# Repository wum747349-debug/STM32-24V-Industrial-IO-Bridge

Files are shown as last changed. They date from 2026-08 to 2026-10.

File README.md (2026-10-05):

# STM32 24V Industrial I/O Bridge

Project Identity: wum747349-debug/STM32-24V-Industrial-IO-Bridge

Hardware Revision: Rev.C

Hardware Status: Fabricated / PCBA Assembled / Basic Functional Bring-up Completed / In Practical Use

Current Project Stage: Stage 6 — Routing and Copper

面向 24 V 工业现场的 STM32 I/O interface / bridge board，连接 PC、板载隔离 USB-UART、STM32、CM35 运动控制器和 4 路 AN-LS18-40-N 光电开关。Rev.C 将 STM32 最小系统、USB-C 通信、数字隔离、现场 I/O 和 24 V 电源保护集成在一块 100 mm × 80 mm PCB 上。

```text
24 V Industrial Power
        |
        v
Input Protection / 24 V -> 3.3 V
        |
        v
      STM32
        |-- Isolated USB-UART (USB-C / CH340C / ISO7721)
        |-- CM35 Motion-controller I/O
        `-- Photoelectric Sensor Interfaces (NO / NC)
```

## Hardware Gallery

| PCB Top | PCB Bottom |
| --- | --- |
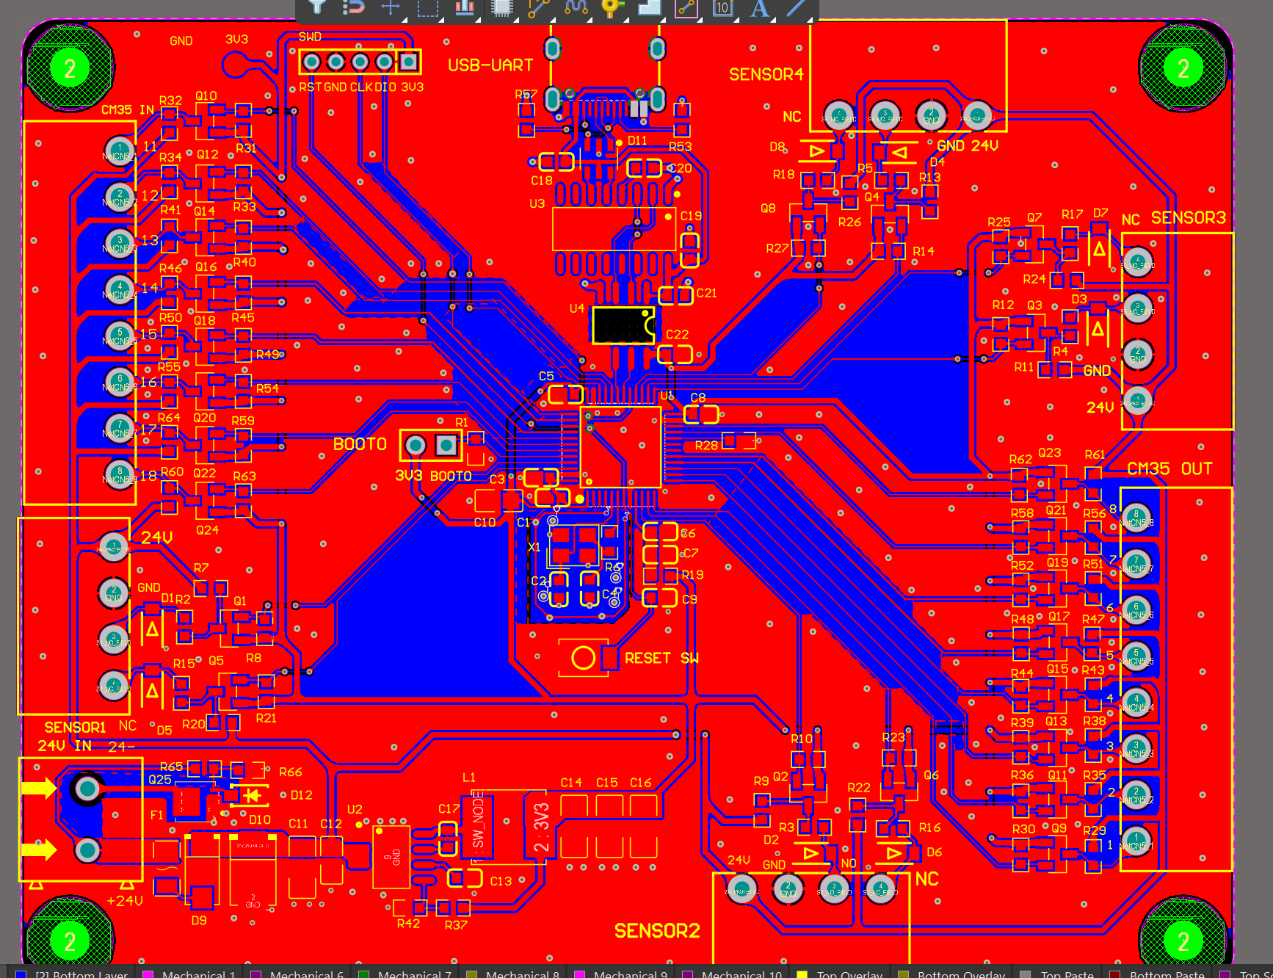
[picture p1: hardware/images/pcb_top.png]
PCB Top
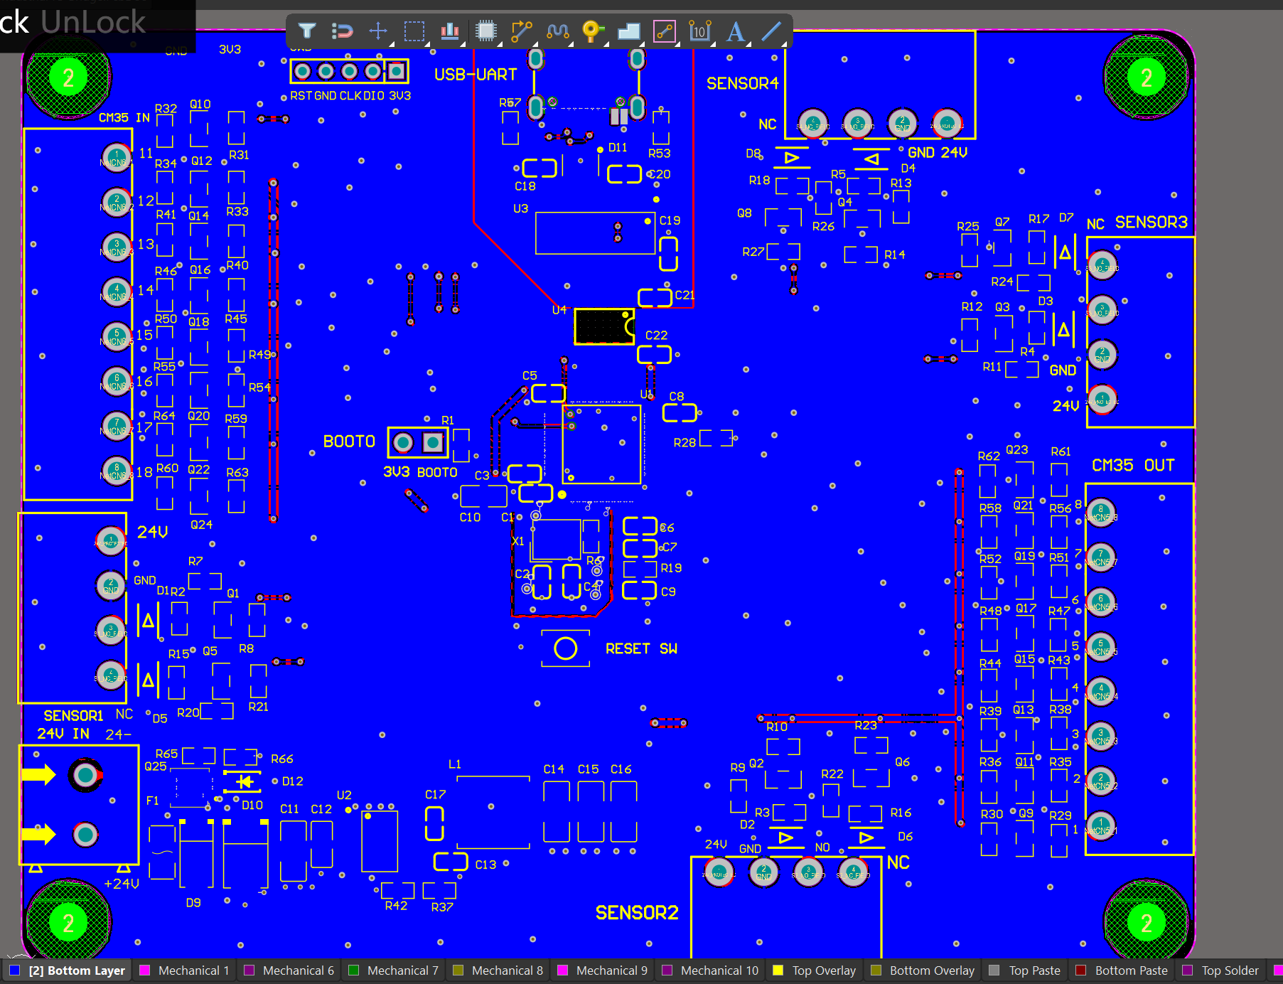
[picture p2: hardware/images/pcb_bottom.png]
PCB Bottom
|  |  |

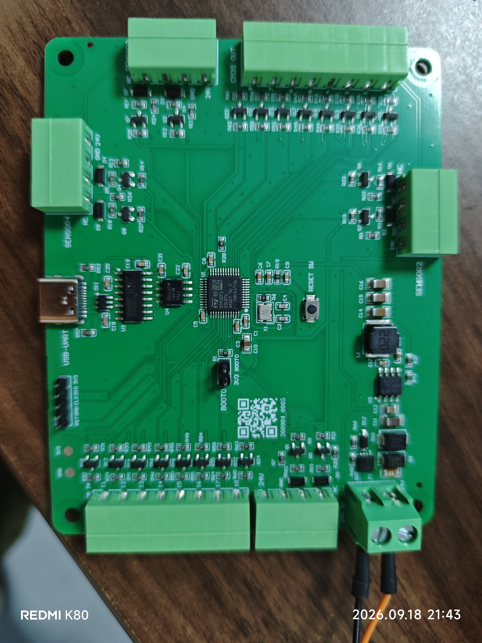
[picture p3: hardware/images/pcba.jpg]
Rev.C PCBA


## Engineering Highlights

- 24 V industrial input with reverse-polarity and input protection, plus onboard 24 V → 3.3 V conversion
- Onboard STM32F103C8T6 minimum system with SWD, reset, BOOT0, HSE, and accessible 3V3/GND test points
- USB-C + CH340C USB-UART with ISO7721 digital isolation and separated USB-side / machine-side ground domains
- Eight CM35 control outputs and eight CM35 status inputs for 24 V industrial I/O
- Four photoelectric-sensor interfaces with field-side power and NO / NC signal paths
- Two-layer PCB layout, signal/power routing, copper pours, isolation corridor, mask normalization, and production-oriented silkscreen
- JLCPCB fabrication / top-side PCBA workflow, followed by board bring-up and practical functional debugging

## Rev.C Hardware Evolution

Rev.C is the third hardware iteration and the current physical implementation. Compared with the previous revision, it:

- adds photoelectric-sensor field power and NO / NC signal interfaces;
- adds onboard USB-C and CH340C USB-UART communication;
- adds ISO7721 isolation between USB-side and machine-side domains;
- replaces the external STM32 minimum-system module with an onboard STM32 minimum system; and
- adds or improves 24 V reverse-polarity, input, and onboard power-conversion protection boundaries.

Detailed revision scope and evidence limits are recorded in [Hardware Revision History](docs/revision_history.md).

## Bring-up and Validation Status

### Confirmed

- Rev.C PCB and assembled PCBA exist and are represented by the images above.
- Basic 24 V power-on and board-level 3.3 V checking were completed.
- STM32 programming through ST-Link was completed.
- Host UART communication was completed at the basic functional-debug level.
- Industrial I/O basic control and terminal-voltage behavior were debugged.
- The board is currently in practical use.

### Not formally documented or claimed

- Complete channel-by-channel quantitative testing
- Quantified input current, startup waveform, ripple, or full-load characterization
- Abnormal-supply qualification
- EMC or surge PASS
- Isolation-withstand PASS
- Complete system acceptance PASS
- Production qualification or product certification

Rev.C has completed practical functional bring-up and is currently in use. Formal quantified validation remains bounded to the evidence documented in this repository; EMC/surge, isolation withstand, full electrical characterization, and complete system acceptance are not claimed. See the [Bring-up Record](docs/bringup_log.md) for the actual sequence, known results, limitations, and recommended future test plan.

## Engineering Status and Evidence Boundaries

- Requirements, component selection, module design, and formal schematic review records are retained in the repository. Stage 4 Formal Schematic Review is recorded as `PASS / CLOSED`, but the project does not claim full-board ERC PASS.
- Full-board placement was closed against the 100 mm × 80 mm mechanical baseline. Stage 6 signal/power routing, polygons, isolation corridor, and finalization work reached final-review level; the lifecycle stage remains **Stage 6 — Routing and Copper**.
- Final DRC on 2026-09-04 reported **0 warnings / 76 rule violations**. The remaining violations were classified as 4 intentional M3 NPTH/keepout scope collisions, 66 minimum solder-mask slivers, and 6 intentional HSE GND-guard net antennae.
- **Final DRC was not zero-violation.** The remaining findings were categorized and reviewed, but this repository does not declare a formal `DRC PASS`.
- JLCPCB production artwork and the PCB/PCBA order were released in September 2026. That historical release state does not replace current hardware-test evidence.
- A minor mechanical note remains for confirming the CN5 / lower-right M3 fastener and removable-terminal envelope with 3D, courtyard, or physical mechanical evidence.

## Repository Navigation

| Area | Record |
| --- | --- |
| Requirements | [requirements.md](requirements.md) |
| Block Diagram | [block_diagram.md](block_diagram.md) |
| Design Notes | [design_notes.md](design_notes.md) |
| Reference Index | [references.md](references.md) |
| Component Selection | [docs/component_selection_plan.md](docs/component_selection_plan.md) |
| Module Design | [docs/module_design/](docs/module_design/) |
| Schematic Review | [docs/schematic_review.md](docs/schematic_review.md) |
| PCB Design Rules | [docs/pcb_design_rules.md](docs/pcb_design_rules.md) |
| PCB Review / DRC / Manufacturing Record | [docs/pcb_review.md](docs/pcb_review.md) |
| Bring-up | [docs/bringup_log.md](docs/bringup_log.md) |
| Revision History | [docs/revision_history.md](docs/revision_history.md) |
| Hardware Sources and Evidence | [hardware/README.md](hardware/README.md) |
| Altium Source Project | [hardware/altium_project/](hardware/altium_project/) |
| Schematic PDF | [hardware/outputs/SCH_Schematic1_2026-09-01.pdf](hardware/outputs/SCH_Schematic1_2026-09-01.pdf) |
| BOM | [hardware/outputs/BOM_Board1_Schematic1_2026-09-01.xlsx](hardware/outputs/BOM_Board1_Schematic1_2026-09-01.xlsx) |
| Framework Binding | [FRAMEWORK.md](FRAMEWORK.md) |
| Project Rules | [PROJECT_RULES.md](PROJECT_RULES.md) |
| Project Validator | [scripts/validate_project_repository.py](scripts/validate_project_repository.py) |

## Current Source and Evidence Set

The current Rev.C Altium project source is versioned under `hardware/altium_project/`. The project file, schematic, PCB, and required project-local libraries are included; generated History, logs, previews, project outputs, manufacturing archives, and temporary files are excluded.

The current Stage 4 schematic PDF and BOM remain under `hardware/outputs/`. Images are presentation and physical-hardware evidence; they do not independently prove connectivity, ERC/DRC status, isolation rating, or quantified electrical performance.

## Next Evidence Work

Future work can add traceable, quantified power measurements, USB-UART power-sequence checks, complete industrial-I/O and sensor channel records, and a formal test report with explicit limits. This portfolio finalization does not perform a Stage transition or convert recommended tests into completed results.

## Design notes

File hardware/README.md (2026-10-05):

# Hardware Sources and Evidence（硬件源与证据）

只有相应工作或 Evidence 真实存在时才创建 hardware 子目录：

- `altium_project/`：权威 `.PrjPcb`、`.SchDoc`、`.PcbDoc` 与必要 Project libraries；
- `outputs/`：可追溯的 schematic PDF、BOM、reports 与 manufacturing outputs；
- `images/`：Review、Assembly、Bring-up、Test 与展示图片。

`.SchDoc` 与 `.PcbDoc` 是权威 EDA implementation sources。目录、PDF、图片或书面设计意图不能证明 ERC、DRC、rule matching、copper state 或 manufacturing release。用户负责实际 Altium 操作与导出；AI/Codex 只在明确限制内分析用户提供的 Evidence。

不得仅为让目录看起来完整而创建空 output 分类或低信息量 placeholder 文件。

## Current Rev.C Altium Source Set

The versioned source set is limited to the files required by the current `STM32 24V Industrial IO Bridge.PrjPcb` project:

- `altium_project/P1.schdoc`
- `altium_project/PCB1.PcbLib`
- `altium_project/STM32 24V Industrial IO Bridge.SCHLIB`
- `altium_project/STM32 24V Industrial IO Bridge/STM32 24V Industrial IO Bridge.PrjPcb`
- `altium_project/STM32 24V Industrial IO Bridge/STM32 24V Industrial IO Bridge.PcbDoc`

The `.PrjPcb` source explicitly references the schematic, both project-local libraries, and the PCB document above. Generated `History`, project logs, previews, project outputs, `.PrjPcbStructure`, backups, temporary ZIP files, Gerber/drill data, and pick-and-place or assembly archives are not part of the public source set.

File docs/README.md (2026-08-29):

# Stage Documents（阶段文档）

本目录保存 Stage-enabled 与 Conditional Project 文档。Bootstrap 不预建这些文件；只有真实活动触发时才创建。

| Path | Responsibility | Enable When |
| --- | --- | --- |
| `component_selection_plan.md` | Critical component candidates and decisions | Stage 2 begins |
| `module_design/*.md` | Module connections, calculations, evidence, risks, layout requirements | A module enters Stage 3 detail design |
| `schematic_review.md` | Actual schematic review evidence, issues, status, conclusion | Stage 4 begins |
| `pcb_design_rules.md` | Project rule values, Scope, Priority, configuration status, waiver definitions | Before Stage 5 Layout Preflight |
| `pcb_review.md` | Layout Preflight, routing issues, user DRC summary, waivers, manufacturing release | Layout Preflight is recorded; maintained through Stages 6–7 |
| `bringup_log.md` | Assembly, first power-on, measurements, debug history | Stage 8 assembly or bring-up activity begins |
| `test_report.md` | Test conditions, results, limits, acceptance conclusion | Stage 8 formal testing begins |
| `revision_history.md` | Hardware revisions, reasons, impact, required revalidation | First hardware revision or material change |
| `user/` | User-facing setup, wiring, interface, and safety guidance | The project requires user documentation |

当前 Project Stage 只在仓库根 `README.md` 维护。文件存在不证明对应 Stage 已通过。

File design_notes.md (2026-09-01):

# Design Notes

本文件记录整板架构、系统级设计意图、接口/跨模块约定和架构权衡；候选方案在形成依据前不得写成已选事实。已有 module design record 负责的逐引脚连接、普通 R/C 值和模块计算无需在此并行维护。

## Board-level Intent

- 新板以 STM32F103C8T6 直接集成为基础，不再依赖外购 minimum-system module；面向 JLCPCB SMT / PCBA。
- USB-to-serial 功能板载，USB-UART 与 STM32 UART 之间采用 galvanic isolation；`USB_GND` 与 machine-side `GND` 不直接共地。
- CM35 实际提供 IN1–IN18 与 OUT1–OUT8；本板使用 IN11–IN18 和 OUT1–OUT8，IN1–IN10 不属于本板控制范围。当前 reserved channels 仍是硬件边界的一部分。
- 上一代 CM35 I/O 功能行为可作为 Legacy Functional Baseline。Stage 2 已检查归档上一代原理图，确认其电平转换主要使用 2N7002 MOSFET networks；用户已明确授权复用该转换思路，但 exact connection、resistor values 和 protection 不自动成为新板已验证事实。
- 用户提供的 CM35 official-manual pages 确认：输入下拉至 `24G` 时为“通”，输入带抗干扰过滤且信号需保持至少约 2 ms；输出接线为负载位于 `+24 V` 与 OUT 之间，因此按 low-side / sinking behavior 处理，不推断未公开的内部 transistor topology。
- CM35 `V/G` 是 I/O 隔离 24 V 供电端，`24V/0V` 是 controller system supply。Rev.A 采用两套独立、隔离输出的 24 V switching PSU：PSU A 只供 CM35 system `24V/0V`；PSU B 直接分配至 CM35 I/O `V/G` 和 PCB `24V/GND`。PCB `GND = CM35 G / 24G = PSU B -V`，不得直接连接 CM35 system `0V`、PSU A `-V`、PE 或 chassis。用户已确认实际设备存在 IN15–IN18。
- 4 个传感器每个都提供 `+24V_PROTECTED / GND / NO / NC` 端子，并采集全部 NO + NC，共 8 路 sensor digital inputs；M5 全 8 路 2N7002 + series resistor + field-side TVS capture 已完成当前会话 screenshot-level completeness review。
- 板级设计优先考虑工业长线保护、safe startup、现场接线可维护性和首次限流上电。

## Current Decisions

| Architecture Fact | Current Position | Basis |
| --- | --- | --- |
| 主控 | STM32F103C8T6 直接集成到 PCB；M2 current-session module closeout acceptable | 用户确认的项目目标；Stage 2 qualification + Stage 3 user/ChatGPT session review |
| CM35 channel scope | CM35 提供 IN1–IN18 / OUT1–OUT8；本板使用 IN11–IN18 / OUT1–OUT8 | 用户确认的系统边界；IN15–IN18 已由用户针对实际设备确认 |
| Protocol polarity | Application `1=Active`; physical GPIO Active-Low; firmware inversion | 已验证系统行为与用户提供的 interface contract |
| CM35 / Sensor conversion | 复用 legacy 2N7002 MOSFET conversion approach；当前保留 LCSC `C7420321`，不要求仅因旧记录而更换为 Nexperia `2N7002,215` | 用户授权 + previous working board evidence + current low-current application acceptance；Nexperia qualification history retained as reference |
| CM35 Rev.A power domain | PSU A -> CM35 system `24V/0V`；独立 PSU B -> CM35 I/O `V/G` + PCB `24V/GND`；`PCB GND = CM35 G / 24G`，且 `PSU A -V != PSU B -V`；不增加 per-channel isolation | CM35 official-manual evidence + 用户最终系统架构决策 |
| M4 module status | 16-channel CM35 interface 与 safe-startup design / current-session capture `CLOSEOUT ACCEPTABLE` | Stage 3 user-provided Altium screenshots；不代表 ERC、footprint 或 Stage 4 结果 |
| Sensor acquisition | 每个传感器独立 `+24V/0V/NO/NC` 端子并采集 NO+NC，共 8 路 inputs | 用户确认；OPEN-002 |
| M5 frontend status | 8-channel capture `CLOSEOUT ACCEPTABLE` | 全 8 路 current-session screenshot-level completeness review + Littelfuse official SMF30A data |
| USB-UART / isolation | USB side `USB_VBUS/USB_GND` ↔ ISO7721DR ↔ STM32 USART1 on machine-side `3V3/GND`; M3 current-session closeout acceptable | Stage 2 selection + Stage 3 manufacturer-data review + user-provided Altium screenshot |
| 24 V input protection | Positive path `24V_IN_RAW -> F1 -> D9 STPS2H100A -> 24V_PROTECTED` plus Q25 `DMT10H015LFG-13` low-side return protection from `GND_IN_RAW` to PCB `GND`, with R65/R66 bias and D12 gate-source clamp | Stage 4 PASS / CLOSED；用户已在 Altium 中完成 Q25 symbol D/G/S ↔ PowerDI3333-8 pads ↔ manufacturer pinout 最终核对 |
| 24 V -> 3.3 V | LMR36510FADDAR synchronous buck | Stage 2 official-source qualification；OPEN-006 |

M1 当前 schematic architecture 已细化并达到 current-session module closeout acceptable；exact connections、values、L1 decision 与 validation boundary 由 `docs/module_design/m1_power.md` 持有。M3 的 exact USB/UART connections、power-state/default behavior、shield termination 与 module-specific layout details 由 `docs/module_design/m3_usb_uart_isolation.md` 持有。M4/M5 的 channel-level mapping、values、connector pin order 与 evidence boundary 分别由 `docs/module_design/m4_cm35_io.md` 和 `docs/module_design/m5_sensor_interface.md` 持有。

## Power and Interfaces

| Domain / Interface | Source | Destination | Required Boundary |
| --- | --- | --- | --- |
| CM35 system power | Isolated-output PSU A | CM35 `24V/0V` only | PSU A `-V` 不得直接连接 PSU B `-V`、PCB `GND`、CM35 `G/24G`、PE 或 chassis |
| Isolated I/O power | Independent isolated-output PSU B | Cabinet-direct CM35 `V/G` distribution + PCB M1 input | `PCB GND = CM35 G / 24G = PSU B -V`；CM35 `V/G` 不经过 PCB F1 |
| PC communication | PC USB | USB-C -> USBLC6-2SC6 -> CH340C -> ISO7721DR -> STM32 USART1 | `USB_GND` 与 machine `GND` 不直接共地；两侧分别由 `USB_VBUS` 与 `3V3` 供电；不得 back-power machine side |
| CM35 control | STM32 GPIO | 2N7002 conversion -> CM35 IN11–IN18 | Shared PSU-B I/O-domain `GND` / `G / 24G` reference；pull-to-24G active；reset/boot safe inactive；M4 closeout acceptable |
| CM35 status | CM35 OUT1–OUT8 | 2N7002 conversion -> STM32 GPIO | Shared PSU-B I/O-domain reference；CM35 low-side / sinking behavior；firmware 转正逻辑 DataOut；M4 closeout acceptable |
| Sensors | 4 × 24 V NPN NO+NC | `24V_PROTECTED` + 2N7002-based input conversion -> STM32 | Same PSU-B I/O domain；8 路 inputs；M5 closeout acceptable |

## Rev.A System Power-domain Architecture

```text
CM35 System Domain
  PSU A +24 V -> CM35 24V
  PSU A -V    -> CM35 0V

Isolated I/O Domain
  PSU B +24 V -> CM35 V             (cabinet terminal distribution)
  PSU B -V    -> CM35 G / 24G       (cabinet terminal distribution)
  PSU B +24 V -> P1 positive -> 24V_IN_RAW -> F1 -> STPS2H100A -> 24V_PROTECTED
  PSU B -V    -> P1 negative -> GND_IN_RAW -> Q25 -> PCB GND
  24V_PROTECTED -> M4 pull-ups / M5 sensors / LMR36510 -> 3V3

Isolation rule: PSU A -V != PSU B -V
```

CM35 `V/G` is not powered through PCB F1 or `24V_PROTECTED`, and the PCB does not add a CM35 `V/G` power-output connector. Exact PSU-B procurement, manufacturer, and current rating remain later system-integration items.

## 24 V Source Evidence Boundary

- 用户提供的现有电源图片标示型号 `MS-120-24`、输出 24 V / 5 A、120 W。
- 用户已用万用表确认当前实际输出约 24 V 且观察较稳定。
- 该信息支持当前 24 V nominal design point，但不是 manufacturer official regulation/surge specification；不得据此声称满足特定 IEC surge 等级或长期 tolerance。
- 外部 PSU 的 5 A capability 不是 PCB input fuse/current-limit rating。板上 overcurrent element 必须按本板实际 load budget 与 fault-energy requirement 另行确定。

## M1 Power Architecture Decision

Current board-level architecture:

```text
PSU B +24V -> P1 positive -> 24V_IN_RAW
  -> 0468.500NRHF 0.5 A / 63 V Slo-Blo fuse
  -> STPS2H100A series reverse-polarity diode
  -> 24V_PROTECTED
       -> SMBJ30A-TR to PCB GND
       -> M4 pull-ups / M5 sensors
       -> LMR36510FADDAR -> 3V3

PSU B -V -> P1 negative -> GND_IN_RAW
  -> Q25 DMT10H015LFG-13 Drain; Source -> PCB GND
     R65 10 kΩ: 24V_IN_RAW -> Gate
     R66 100 kΩ: Gate -> Source / PCB GND
     D12 MMSZ5242B-7-F: Cathode -> Gate; Anode -> Source / PCB GND
```

- LMR36510FADDAR is a 4.2–65 V, 1 A synchronous buck with high-voltage transient tolerance class suitable for this nominal 24 V architecture.
- SMBJ30A-TR uses a 30 V stand-off level so it remains off at the measured ~24 V operating point while providing transient suppression below the converter absolute high-voltage boundary under the currently assumed source conditions.
- The low-side Q25 correction covers the actual fault case in which CM35 signal wiring remains connected while both PCB 24 V input wires are reversed. `GND_IN_RAW` must not be merged with or routed around Q25 to PCB `GND`.
- The current-session schematic evidence supports this corrected topology. The user completed the final Q25 schematic-symbol D/G/S to PowerDI3333-8 pad and manufacturer-pinout check in Altium; SR-M1-001 is closed.
- C14/C15/C16 are Samsung `CL31B226KPHNNNE`, LCSC `C87996`, 22 uF, 10 V, X7R, 1206 buck output capacitors; obsolete X5R wording no longer applies.
- M1 current-session module design / EDA capture closeout is acceptable；exact values and remaining validation boundaries are maintained in `docs/module_design/m1_power.md`，not duplicated here.
- Exact surge waveform/source impedance, startup/inrush coordination、capacitor DC-bias、thermal and layout verification remain open；no compliance claim is made.

## Stage-2 Bounding Power Budget

本预算只用于 PCB branch 及其 board-powered loads 的关键器件 current-class selection；它不是 Stage-3 ripple、magnetics、startup 或 thermal calculation，也不是包含 CM35 I/O consumption 在内的完整 PSU-B cabinet-supply sizing value。本 transaction 不重新计算或指定 PSU-B rating。

| Load | Stage-2 allowance | Basis / limitation |
| --- | ---: | --- |
| 4 × AN-LS18-40-N sensor supply | ≤40 mA @ 24 V | User-provided manual states ≤10 mA each；manufacturer provenance provisional |
| CM35 16-channel interface circuitry | 80 mA @ 24 V | Conservative PCB-side 5 mA/channel allocation；exact CM35 input current/output-load parameters remain formal-review inputs and do not size the complete PSU-B cabinet supply |
| STM32F103C8T6 | 60 mA @ 3.3 V | Conservative architecture allowance, not an operating-point prediction |
| ISO7721 machine-side supply | 10 mA @ 3.3 V | Includes logic-rate allowance |
| Machine-side pull-ups / interface logic | 40 mA @ 3.3 V | Bounding allocation pending exact values |
| Indicators / ordinary support | 40 mA @ 3.3 V | Optional-support allowance |
| 3.3 V engineering reserve | 100 mA @ 3.3 V | Raises the 3.3 V design envelope to 250 mA |

At 24 V and a deliberately conservative 75% buck-efficiency assumption, 250 mA at 3.3 V corresponds to about 46 mA input. Sensors + CM35 allocation + buck input total about 166 mA; the Stage-2 24 V continuous design envelope is rounded up to **225 mA**, leaving about 59 mA additional board-level reserve.

The historical CM35 interface allocation in this Stage-2 envelope bounded PCB-side interface pull-ups and related board circuitry; it must not be interpreted as the complete cabinet-distributed CM35 `V/G` supply current. Final PSU-B sizing must include the actual CM35 I/O-domain load separately.

## Stage 3 Cross-Module Integration Closeout

- Power Flow: PSU A and PSU B domains are explicitly separated; the PSU-B PCB branch enters M1 as `24V_IN_RAW` / `GND_IN_RAW`, with Q25 separating the raw negative input from PCB `GND`, then feeds `24V_PROTECTED`, sensors, M4 pull-ups, and `3V3`, while CM35 `V/G` is cabinet-fed directly.
- Signal / Control Flow: USB-UART, STM32, CM35 IN/OUT, and all eight sensor NO/NC mappings are recorded without responsibility gaps.
- Voltage / Logic Compatibility: M4 and M5 retain the reviewed 2N7002 Active-Low translation; USB/machine isolation remains unchanged.
- Startup / Shutdown / Fault State: M4 safe-startup remains hardware-enforced; USB back-power and unverified transient/thermal behavior remain explicit later-review boundaries.
- Cross-sheet Net Consistency: current-session visible evidence uses `24V_IN_RAW`, `GND_IN_RAW`, `24V_PROTECTED`, `3V3`, `GND`, `USB_GND`, and the recorded channel names consistently; this is screenshot/PDF evidence, not `.SchDoc` object parsing or footprint mapping verification.
- Missing / Conflicting Responsibility: no Stage-3 module responsibility conflict remains. The complete same-date schematic PDF and BOM are archived under `hardware/outputs/`; Stage 4 Formal Schematic Review is **PASS / CLOSED** and PCB Layout entry is approved.

- LMR36510FADDAR：0.25 A output envelope versus 1 A rating → current-class margin PASS。
- STPS2H100A：0.225 A input envelope versus 2 A rating → current-class margin PASS；exact forward-loss/thermal verification remains Stage 3。
- External PSU 5 A capability is not used in this calculation.

## F1 Overcurrent Decision

- Primary：Littelfuse `0468.500NRHF`，0.5 A / 63 V，1206 Slo-Blo fuse，LCSC C206993。
- Manufacturer basis：50 A interrupting rating at 63 VAC/VDC；time-delay behavior is specified to tolerate inrush. Littelfuse requires a standard 25% continuous-operation derating plus temperature re-rating. At 70°C the datasheet example gives usable continuous current `0.75 × 0.80 × 0.5 A = 0.30 A`, still about 33% above the 0.225 A envelope.
- Startup boundary：0.5 A is accepted because the time-delay characteristic provides input-capacitor/startup tolerance without moving immediately to a 1 A class. Final startup/inrush and local-temperature evidence remain later verification inputs. If allowable continuous current falls to or below 0.225 A, or startup nuisance opening is predicted, reassess the 468 Series 1 A member and verify its exact orderable MPN rather than silently changing F1.
- Fault boundary：the 50 A interrupt rating does not by itself prove coordination with the PSU peak fault current or field wiring；those source/fault-path inputs remain unverified, and no system safety-standard claim is made.
- Alternate architecture：Littelfuse `1210L035/60PR` PPTC，0.35 A hold / 0.70 A trip at 20°C，60 V max，10 A max fault current. It is not Primary because hold current falls to 0.24 A at 60°C and 0.21 A at 70°C, its resistance can rise to 1.5 Ω after trip/reflow, it dissipates about 1.5 W tripped, and it continues residual current during a sustained fault. Use only after application-temperature、voltage drop/heating、trip/recovery and sustained-fault verification.

## M3 Isolation Architecture Decision

- M3 keeps the PC USB domain (`USB_VBUS/USB_GND`) galvanically isolated from the machine domain (`3V3/GND`) through ISO7721DR; `USB_GND` must not connect directly to machine `GND`.
- STM32 USART1 remains PA9 = `MCU_UART_TX` and PA10 = `MCU_UART_RX`; M3 current-session module closeout is acceptable.
- Exact USB-C / USBLC6-2SC6 / CH340C / ISO7721 connections, channel direction, default-HIGH / power-state reasoning, shield termination and module-specific layout constraints are owned by `docs/module_design/m3_usb_uart_isolation.md` and are not duplicated here.

## Pin and Connection Planning

只有真实 Project decision 已形成依据时，才记录 board-level pin/function constraints、项目网络名或跨模块 mapping；module-specific pin-by-pin implementation 由启用后的 module design record 维护。

| Function | Required Direction / Behavior | Frozen Mapping | Basis |
| --- | --- | --- | --- |
| CM35 IN11–IN18 control | 8 outputs; LOW=Active, HIGH=Inactive | PB0 / PB1 / PB5 / PB6 / PB7 / PA8 / PA11 / PA12 | M4 external network must enforce safe inactive startup |
| CM35 OUT1–OUT8 status | 8 inputs; LOW=Active, HIGH=Inactive | PA0–PA7 | Preserves one-to-one EXTI0–EXTI7 allocation |
| USB-UART | Bidirectional USART1 | PA9 = MCU_UART_TX；PA10 = MCU_UART_RX | STM32 ↔ ISO7721DR ↔ CH340C；M3 current module closeout acceptable |
| Sensor inputs | 4 × (NO+NC) = 8 inputs | PB8–PB15 | Preserves one-to-one EXTI8–EXTI15 allocation |
| SWD | Programming and debug | PA13 = SWDIO；PA14 = SWCLK | 1×5 current interface also carries VTREF / 3V3, GND and NRST |
| Boot / clock | Main Flash baseline；8 MHz HSE | PB2 = BOOT1；PD0 = OSC_IN；PD1 = OSC_OUT | BOOT0/BOOT1 default LOW；LSE not fitted |

PA0–PA7 and PB8–PB15 intentionally avoid EXTI line-number conflicts across all 16 external inputs. PA15 / PB3 / PB4 are SWJ/JTAG-related pins at reset；future GPIO use requires firmware to release JTAG resources. M2 does not depend on MCU reset GPIO state for CM35 safety: M4 implements the cross-module contract `MCU high-Z -> 3V3 pull-up -> 2N7002 OFF -> 24 V side HIGH -> CM35 inactive`; current-session screenshots support module closeout, while `.SchDoc` parsing、ERC and hardware behavior remain unverified.

## PCB Inputs

- Mechanical constraints：M4 CM35 使用 3.81 mm 8P pluggable terminal，M5 Sensor 使用 3.81 mm 4P pluggable terminal；final mating、board-edge access、enclosure 与 mechanical acceptance 仍后置到 Stage 5 Layout Preflight。
- Sensitive or high-risk areas：24 V input protection、long-line CM35/Sensor I/O、USB/machine isolation boundary、clock/VDDA、reset/boot、安全默认状态。
- Power and thermal constraints：Stage-2 bounding load budget 与 F1 current class 已关闭；M1 Stage-3 external values and L1 are recorded, while exact capacitor qualification、thermal、startup 与 TVS/fuse interaction remain later validation items。
- M3 layout boundary：USBLC6 靠近 USB-C，USB ESD return 保持短；CH340C 与 ISO7721 decoupling 靠近对应 pin；不得用 copper/pour/via/test point 跨接 `USB_GND` 与 `GND`；isolator barrier 区域保持所需 creepage/clearance。
- Required official layout sources：STM32、CH340C、ISO7721DR、LMR36510、STPS2H100A、SMBJ30A、USBLC6-2SC6、2N7002 及 CM35/Sensor external-interface data。

## Open Decision References

Open Question 与 decision status 只在 `requirements.md` 的 `OPEN-xxx` 表维护。本文件仅记录架构影响，不建立第二套状态：OPEN-005/006 已在 Stage 2 形成 architecture decision；OPEN-007/008 已在 Stage 3 关闭；OPEN-003/004/009/010 仍按 `requirements.md` 维护。

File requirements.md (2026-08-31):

# Requirements Baseline

本文件保存 Stage 1 第一版需求边界。已确认内容来自用户提供的项目事实；未知事实保持 `TBD` / `待确认`，不构成器件选型、原理图实现或验证结论。

## Project Goal

设计 STM32F103C8T6 直接板载的 24 V 工业 I/O 中继与接口板，实现 C# 上位机经 USB / 板载 USB-UART 与 STM32 通信、STM32 与 CM35 之间 8 路控制及 8 路状态回读，并为 4 个 AN-LS18-40-N 光电开关提供独立现场接口和 24 V 供电。设计应改善现场接线、保护、调试和 PCBA 适配性，同时保留已经实际设备验证的 CM35 系统级功能行为作为 Legacy Functional Baseline。

## Out of Scope

- Requirements Baseline 不负责维护器件候选或最终 BOM；Stage 2 关键选型由 `docs/component_selection_plan.md` 维护。
- exact resistor / RC、buck magnetics、GPIO/USART allocation、普通外围与逐引脚连接属于 Stage 3；connector / enclosure / PCB mechanics 在 Layout Preflight 前冻结。
- 不创建或修改 `.SchDoc`、`.PcbDoc`，不执行 EDA drawing、PCB design、firmware implementation 或 manufacturing output。
- 不声称 ERC、DRC、Repour、PCBA、Bring-up 或实测已完成。
- 不把上一代 schematic / BOM 作为本项目当前 EDA authority，也不把旧器件未经重新 qualification 直接冻结为新设计。

## Functional Boundary

- 系统链路：C# 上位机 ↔ USB ↔ 板载 USB-UART ↔ STM32 ↔ CM35。
- CM35 实际提供 IN1–IN18 与 OUT1–OUT8；本 Project 只控制 IN11–IN18，并回读 OUT1–OUT8。IN1–IN10 不属于本板控制范围。
- CM35 控制：保留 8 路 STM32 → CM35 IN11–IN18 控制通道。
- CM35 回读：保留 8 路 CM35 OUT1–OUT8 → STM32 状态通道，包括当前保留通道。
- 传感器：连接 4 个相同 AN-LS18-40-N，每个传感器具有独立 `+24V / 0V / NO / NC` 现场端子；NO 与 NC 均采集，共 8 路 MCU sensor digital inputs。
- 板载功能：STM32F103C8T6 最小系统、板载 USB-UART、24 V 输入与保护、低压供电、SWD / 调试与必要测试入口。
- 固件负责把 Active-Low 物理 GPIO 语义转换为正逻辑协议语义；本项目本阶段只记录接口契约，不实现固件。

## Module Boundary

| Module | Stage 1 Responsibility |
| --- | --- |
| M1 — 24V Input / Protection / Low-voltage Power | `0468.500NRHF` F1 → `STPS2H100A` → protected 24 V bus，`SMBJ30A-TR` 跨接保护，`LMR36510FADDAR` 产生 machine-side 3.3 V；exact external values 留待 Stage 3。 |
| M2 — STM32F103C8T6 Minimum System | 集成 MCU 本体及后续所需的供电、VDDA、reset、boot、clock、SWD、调试与安全启动边界。 |
| M3 — USB-UART Communication | `USBLC6-2SC6` + `CH340C` 经 `ISO7721DR` 连接 machine-side STM32 UART；USB-C mechanical acceptance 与 exact USART/pins 后置。 |
| M4 — CM35 Industrial I/O Interface | 8 路 STM32 → IN11–IN18 控制与 8 路 OUT1–OUT8 → STM32 回读。 |
| M5 — Photoelectric Sensor Interface | 为 4 个 AN-LS18-40-N 供电，并通过 2N7002 / 100 Ω / field-side SMF30A 前端接收每个传感器的 NO + NC，共 8 路输入；当前 capture closeout acceptable。 |
| M6 — Connectors / SWD / Indicators / Test Points | 提供便于现场接线、编程、调试和安全首次上电的物理入口；指示功能范围待确认。 |

## Power Requirements

- 外部机器电源为 24 V DC。
- 24 V 输入必须经过保护后形成 protected 24V bus；该 bus 至少服务 CM35 interface、4 个光电开关与板上低压电源。
- 板上采用 LMR36510FADDAR 从 protected 24 V bus 产生 STM32 与机器侧逻辑所需 3.3 V；Stage-2 output design envelope 为 0.25 A，exact magnetics / capacitors / thermal 留待 Stage 3。
- 24 V Primary protection chain 为 `0468.500NRHF` 0.5 A / 63 V time-delay fuse、`STPS2H100A` series reverse-polarity diode 与 `SMBJ30A-TR` TVS；不得用外部 PSU 的 5 A capability 作为 PCB fuse rating。
- USB 供电不得意外反向供电 machine-side power system。
- 首次上电必须支持安全的限流测试流程；实际限流值与步骤待后续设计和 Bring-up 计划确定。
- 4 个传感器由板上 protected 24V bus 供电；Stage-2 暂按用户提供 manual 的 static current `≤10 mA each`，合计 provisional `≤40 mA`，manufacturer provenance 与 Stage-3 exact frontend qualification 仍未关闭。

## Interface Requirements

### PC / USB / UART

- 采用 board-mounted USB-UART，尽量复用现有串口帧与 C# 上位机 communication model。
- USB-UART 与 STM32 UART 之间必须采用 galvanically isolated UART interface；PC USB ground 与 machine-side 24 V `0V` 不直接共地。
- Stage-2 Primary 为 TYPE-C-31-M-12（mechanical-conditional）、CH340C、USBLC6-2SC6 与 ISO7721DR；exact USART/GPIO、USB-C mechanical acceptance、power-state 与 back-power implementation 留待对应后续阶段。

### STM32 → CM35（IN11–IN18）

- 保留 8 路硬件通道；用户提供的 CM35 official-manual pages 确认输入信号线连接/下拉至 `24G` 时为“通”，即 active-low / sink-to-24G behavior；资料同时说明输入带抗干扰过滤，信号需保持至少约 2 ms 才能可靠识别。
- Protocol / Application contract：`DataIn = 1` 表示 Active，`DataIn = 0` 表示 Inactive。
- Physical controller-output GPIO contract：`LOW = Active`，`HIGH = Inactive`；极性转换属于 STM32 firmware。
- 上一代 2N7002 下拉实现作为 Legacy Design Reference；用户已在 Stage 2 明确授权复用该转换思路，新原理图仍必须根据当期器件与官方资料重新 qualification。

### CM35 → STM32（OUT1–OUT8）

- 保留 8 路硬件通道；用户提供的 CM35 official-manual pages 显示负载连接在 `+24 V` 与 `OUT1–OUT8` 之间，因此输出按 low-side / sinking behavior qualification；没有证据时不进一步声明内部 transistor topology。Stage 2 对归档旧原理图的检查另确认 legacy readback 使用 2N7002 MOSFET networks，而不是 optocoupler。
- 上一代系统行为仍为 CM35 Active → STM32 GPIO LOW，Inactive → GPIO HIGH；Stage 3 已定义 2N7002 + 10 kΩ / 10 kΩ、无默认 RC 的 Rev.A baseline。由于 CM35 exact threshold/current/VOL/leakage 参数仍不可得，后续正式审查仍须保留 electrical-limit verification boundary。
- Protocol / Application contract：`DataOut = 1` 表示当前状态 Active，`DataOut = 0` 表示 Inactive。
- firmware 必须执行 Active-Low → positive protocol semantic inversion。
- CM35 `V/G` 是 I/O 隔离 24 V 电源正/负端，`24V/0V` 是 controller system supply；官方资料建议二者使用隔离、不共地的 switching supplies。Rev.A 采用 PSU A 为 CM35 system `24V/0V` 供电，采用独立隔离输出的 PSU B 直接分配至 CM35 I/O `V/G` 与 PCB `24V/GND`。PCB `GND = CM35 G / 24G = PSU B -V`；该节点不得直接连接 CM35 system `0V`、PSU A `-V`、PE 或 chassis。

### CM35 Handshake Protocol — Version B

| CM35 Input | Meaning / Encoding |
| --- | --- |
| IN11 | Start Request：OFF=无效，ON=启动请求有效 |
| IN12 | Scan Mode：OFF=正式扫描，ON=参考扫描 |
| IN13 / IN14 | Reference Count Encoding：`00=3`、`01=5`、`10=8`、`11=12`；仅参考扫描使用 |
| IN15 | Scan Length：OFF=8 mm，ON=15 mm |
| IN16 | Scan Speed：OFF=20 mm/min，ON=30 mm/min |
| IN17 | Reserved / Spare；保留硬件通道 |
| IN18 | Reserved / Spare；保留硬件通道 |

- IN11 只表示 Start Request；IN12 只选择 Formal / Reference Scan；IN16 只选择速度。
- 用户已明确确认实际使用的 CM35 存在 IN15–IN18；局部手册页面只显示较少通道时不得据此删除这些通道。
- Formal scan 不使用 IN13 / IN14；启动前必须先设置 length 与 speed。
- Reference scan 启动前必须先设置 length、speed 与 reference-count encoding。

| CM35 Output | Meaning |
| --- | --- |
| OUT1 | BUSY — 运动执行中 |
| OUT2 | SYNC — 采集同步脉冲 |
| OUT3 | DONE — 扫描段结束脉冲 |
| OUT4 | FAULT — 故障 / 保护信号 |
| OUT5–OUT8 | Reserved；必须保留硬件通道 |

### Photoelectric Sensors

- 4 个用户已购 AN-LS18-40-N：M18 laser diffuse-reflective、NPN、4-wire NO + NC、DC 10–30 V、检测距离 30–400 mm。
- 用户提供的接线定义：Brown=`+24V`、Blue=`0V`、Black=`NO`、White=`NC`；后续连接前仍需以可追溯的正式资料核对。
- 每个传感器使用独立 `+24V / 0V / NO / NC` 端子。
- 现场长线输入必须考虑 ESD / transient / noise、input current limiting / protection，并可考虑 RC / hardware filtering；无需高速数字输入。
- 具体采用 transistor、Schmitt buffer、comparator 或 optocoupler 留待 Stage 2/3。
- 每个传感器的 NO + NC 均采集：4 个传感器共 8 路 MCU sensor digital inputs。

## Safety Boundary

- MCU reset、boot、firmware not ready 及任何上电瞬态期间，全部 CM35 control 必须保持 OFF / inactive，不得触发 CM35 输入误动作。
- 外部 24 V、CM35 与 Sensor 长线接口必须考虑反接、ESD、surge/transient、噪声和故障传播。
- USB-UART 与 STM32 UART 之间的 galvanic isolation 是已确认架构要求，用于隔离 PC USB ground 与 machine-side 24 V `0V`；具体器件、额定值与实现仍需后续 qualification。
- USB 侧不得意外 back-power 机器侧；不同电源域之间的掉电、插拔与 fault state 必须在后续设计中验证。
- 首次上电使用可限流电源并分阶段验证；具体安全 procedure 后续建立，当前未执行实物上电。
- 本 Stage 1 不声称满足任何未定义的法规、functional safety 或 isolation rating；如项目需要，须由用户另行确认适用标准。

## Manufacturing Baseline

- JLCPCB / LCSC preferred；PCB assembly 以 JLCPCB SMT / PCBA 为优先目标。
- MCU 与主要器件尽量直接 SMT，减少人工焊接；connector 的 SMT / THT 取决于后续装配和机械 qualification。
- 器件应尽量具备嘉立创可采购/可贴装性，但具体库存、料号与替代方案属于 Stage 2。
- CM35 IN11–IN18、OUT1–OUT8 使用便于现场接线的 terminal block；4 个 Sensor 各使用独立 4-wire terminal；24 V 输入使用独立 terminal。
- CM35 / Sensor connector electrical family and pitch 已基本确定为 3.81 mm pluggable terminal；matching plug、board-edge access、enclosure 与 final mechanical acceptance 仍待 Stage 5 Layout Preflight。
- PCB layer count、板厚、铜厚、尺寸、安装孔、enclosure 与 mounting constraints 均待确认。

## Acceptance Criteria

| ID | Requirement | Verification Method | Expected Result |
| --- | --- | --- | --- |
| REQ-001 | Repository 使用 `FRAMEWORK.md` 中当前有效 Release + immutable Commit binding 并保持 Standalone Project 结构，同时保留 initialization provenance | Project Validator + 人工核对 | binding、Required files、导航与状态一致，无 Template residue；Initialization Framework Release 仍可追溯 |
| REQ-002 | 具有 8 路 STM32 → CM35 IN11–IN18 硬件通道 | 后续原理图审查与硬件测试 | 8 路均存在，含 IN17/IN18 reserved channels |
| REQ-003 | 具有 8 路 CM35 OUT1–OUT8 → STM32 硬件通道 | 后续原理图审查与硬件测试 | 8 路均存在，含 OUT5–OUT8 reserved channels |
| REQ-004 | 保持 Version B handshake mapping 与时序前置规则 | Firmware/interface review + integration test | IN/OUT mapping、scan prerequisites 与协议语义一致 |
| REQ-005 | 保持协议正逻辑与物理 Active-Low 的跨层契约 | Schematic / firmware / PC software interface review | DataIn/DataOut 的 `1=Active`，GPIO Active-Low inversion 明确且一致 |
| REQ-006 | reset、boot、firmware not ready 时 CM35 controls 为 inactive | 后续原理图分析、上电与 fault-injection test | 不发生 CM35 输入误动作 |
| REQ-007 | 4 个传感器各有独立 `+24V/0V/NO/NC` 现场端子，并采集全部 NO + NC | 原理图/PCB审查与接线检查 | 四组接口完整、标识清晰，共 8 路 MCU sensor digital inputs |
| REQ-008 | 传感器长线输入具备与工业环境相适应的保护/限流/抗噪声设计 | 后续设计审查与测试 | 设计依据可追溯；测试条件与结果后续定义 |
| REQ-009 | 板载 USB-UART 经 galvanically isolated UART interface 连接 STM32 | 后续原理图审查、隔离边界检查与通信测试 | 无需外置 USB-to-serial module；PC USB ground 与 machine-side 24 V `0V` 不直接共地；现有通信模型可评估复用 |
| REQ-010 | USB 不得 back-power machine-side power system | Power-state review + 插拔/掉电测试 | 所有相关供电状态下无非预期反向供电 |
| REQ-011 | 24 V 输入保护并建立 protected 24V bus 与逻辑低压电源 | 后续设计审查与上电测试 | 保护与供电架构有官方依据，满足已确认负载与 fault boundary |
| REQ-012 | CM35、Sensor 和 Power terminals 适合现场接线 | Mechanical/PCB review + 装配检查 | pitch/系列经确认，接线与维护可达性满足用户约束 |
| REQ-013 | 面向 JLCPCB / LCSC 与 SMT / PCBA | BOM/DFM/装配审查 | 关键器件和装配路线可采购、可制造；例外有明确记录 |
| REQ-014 | 首次上电可安全限流测试 | Bring-up plan review + 用户执行 | 有分阶段限流步骤、预期与停止条件；当前尚未执行 |

## Open Questions

| ID | Question | Impact | Decision Needed By | Owner / Source | Qualification / Confirmation Plan | State |
| --- | --- | --- | --- | --- | --- | --- |
| OPEN-001 | USB-UART 是否进行 galvanic isolation？ | 决定 ground loop、噪声、故障传播、电源域和 BOM | Resolved in Stage 1 | 用户确认 | 采用 board-mounted USB-UART + galvanically isolated UART interface；Stage 2 Primary 为 CH340C + ISO7721DR，Stage 3 继续核对 power-state/back-power behavior | Closed |
| OPEN-002 | 每个传感器读取 NO only 还是 NO + NC？ | 决定 MCU 输入数量、前端通道数、端口资源与诊断能力 | Resolved in Stage 1 | 用户确认 | 每个传感器 NO + NC 均采集，4 × 2 = 8 路 MCU sensor digital inputs；exact frontend 已在 M5 Stage-3 record 关闭 | Closed |
| OPEN-003 | USB connector 具体机械型号是否接受？ | 影响机械可靠性、装配、外壳和线缆；不改变已选 USB2.0 architecture | Before Stage 5 Layout Preflight | 用户 / Mechanical | Stage 2 conditional candidate 为 TYPE-C-31-M-12；按 enclosure / 板边 / 插拔约束完成 mechanical acceptance | Open |
| OPEN-004 | CM35 / Sensor / Power terminal 最终 pitch 和系列？ | 影响板尺寸、现场接线、装配方式与成本；不阻断当前 interface class | Before Stage 5 Layout Preflight | 用户 / Mechanical / JLCPCB capability | CM35 / Sensor electrical family and pitch 已基本确定为 3.81 mm pluggable terminal；继续确认 matching plug、board-edge access、enclosure 与 final mechanical acceptance | Open |
| OPEN-005 | 24 V input protection architecture？ | 影响反接、surge/transient 能力、压降、热与安全 | Resolved in Stage 2 | 用户 measurement + Stage 2 qualification | 采用 0468.500NRHF 0.5 A Slo-Blo fuse + STPS2H100A + SMBJ30A-TR + protected 24V bus；exact startup/time-current、surge waveform/source impedance 与 thermal margin 留待 Stage 3 | Closed |
| OPEN-006 | 24 V → 3.3 V power architecture？ | 影响效率、热、噪声、布局、成本与可采购性 | Resolved in Stage 2 | Stage 2 qualification | Primary 采用 LMR36510FADDAR 65 V / 1 A class synchronous buck；Stage-2 0.25 A output envelope PASS，exact inductor/FB/capacitors/ripple/thermal 留待 Stage 3 | Closed |
| OPEN-007 | exact GPIO / USART pin allocation？ | 影响通道数量、boot/debug、安全状态与 PCB routing | Resolved in Stage 3 | M2 module design + M3/M4/M5 integration | GPIO / USART mapping 已在 M2 冻结，并已被 M3 isolated UART、M4 CM35 I/O 与 M5 Sensor Interface 使用 | Closed |
| OPEN-008 | exact CM35 / Sensor external-interface values and protection network？ | 影响阈值、保护、功耗与抗扰度；Stage-2 topology 已确定 | Resolved in Stage 3 | Stage 3 module design + current-session screenshot evidence + Littelfuse official data | M4 16-channel baseline 与 isolated PSU-B I/O domain 已关闭；M5 全 8 路 2N7002 / 100 Ω / SMF30A / no-RC implementation 已完成当前会话 screenshot-level completeness review | Closed |
| OPEN-009 | enclosure / PCB size / mounting constraints？ | 影响 connector 布局、板框、安装孔、散热和可维护性 | Before Stage 5 Layout Preflight | 用户 / Mechanical | 收集可用空间、安装方式、禁布区、固定点及接线方向并确认 | Open |
| OPEN-010 | 是否需要 indicator LEDs / additional diagnostic interface？ | 影响 GPIO、电源预算、面板可见性和调试效率；属于 ordinary peripheral scope | Stage 3 module planning | 用户 / Serviceability | 定义必须显示的 power/communication/I/O/fault 状态和可见性需求；未决定不阻断 Stage 2 | Open |

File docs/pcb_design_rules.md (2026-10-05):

# PCB Design Rules

Document Status: **CONFIRMED RULE BASELINE — STAGE 6 ROUTING/COPPER IMPLEMENTED — DRC EXECUTED — FINAL PCB REVIEW PENDING**

Project Stage: **Stage 6 — Routing and Copper**

This file owns the Project PCB rule and routing/copper baseline. Stage 4 Formal Schematic Review is **PASS / CLOSED** and Stage 5 Placement is **PASS / CLOSED**. Stage 6 routing, polygon implementation and GND-via stitching are substantially complete from user-provided Altium evidence. The active `.PcbDoc` remains the implementation authority. DRC has now been executed, but a formal all-violations-cleared DRC PASS and manufacturing release are not yet claimed.

## Current Inputs and Evidence Boundary

- Current complete schematic: `hardware/outputs/SCH_Schematic1_2026-09-01.pdf`.
- Current BOM: `hardware/outputs/BOM_Board1_Schematic1_2026-09-01.xlsx`.
- Formal schematic review: `docs/schematic_review.md`.
- Placement / routing / copper review record: `docs/pcb_review.md`.
- Hardware Revision: `Rev.C`.
- User-provided Altium screenshots and exported DRC reports are valid interactive engineering evidence.
- The current `.PcbDoc` remains the object-level PCB implementation authority.
- No Gerber/manufacturing-output PASS, hardware-test PASS, EMC/surge result, or final manufacturing release is claimed here.

## Confirmed Electrical and Domain Constraints

| Area | Confirmed constraint | PCB implication |
| --- | --- | --- |
| M1 positive input | `24V_IN_RAW -> F1 -> D9 -> 24V_PROTECTED` | Preserve protection sequence and direct current path |
| M1 negative input | `GND_IN_RAW -> Q25 -> PCB GND` | `GND_IN_RAW` must never bypass Q25 into PCB `GND` through copper, polygon, via, mounting feature, shield or harness |
| M1 buck | U2 LMR36510 VIN/PGND, SW/BOOT, output and FB loops | Keep input/current loops compact; keep `SW_NODE` local; keep FB away from switching copper |
| M2 MCU | STM32F103C8T6 decoupling, VDDA, HSE, reset, SWD | Preserve local routing/return structure; no noisy crossing through protected HSE area |
| M3 isolation | `USB_GND != GND` across ISO7721DR | No copper, plane, via, shield path, test point, mounting feature or other object may bridge domains |
| M3 USB | USB-C -> USB protection -> CH340C -> ISO7721 | Keep D+/D- short/local; preserve ESD return and domain boundary |
| M4 supply domain | PCB `GND = CM35 G / 24G = PSU B -V` | Must remain separate from CM35 system `0V`, PSU A `-V`, PE and chassis |
| M4 connectors | left `CN6 = IN11–IN18`; right `CN5 = OUT1–OUT8` | Preserve current physical topology and routing-driven mapping |
| M5 connectors | `CN1`–`CN4` = Sensors 1–4 | Preserve local frontend / edge topology unless final review finds a real defect |

## Manufacturing and Stackup Baseline

| Item | Current value |
| --- | --- |
| Target fabricator / service | JLCPCB standard 2-layer manufacturing / SMT assembly target |
| Material | FR-4 |
| Layer count | 2 |
| Finished thickness | 1.6 mm |
| Copper | Top 1 oz / Bottom 1 oz |
| Controlled impedance | Not declared; USB geometry is routing guidance, not an impedance guarantee |
| Special via process | No blind/buried vias; no via-in-pad |

## Mechanical Baseline

| Item | Current value / status |
| --- | --- |
| Board | **100 mm × 80 mm**, R3 corner fillets |
| Mounting | **4 × M3 NPTH**, 3.20 mm drill, No Net |
| Nominal hole positions | centers 4 mm from adjacent board edges: `(4,4)`, `(96,4)`, `(4,76)`, `(96,76)` mm when lower-left is origin |
| Mounting keepout | approximately **Ø7.0 mm solid Keepout Region**, restricting copper / track / via / pads around each mounting hole |
| Connector topology | CN1–CN6, P1 and USB-C remain at board edges according to current Stage 5/6 topology |
| Remaining mechanical note | later check `CN5` versus bottom-right M3 screw/head/washer/mating-plug envelope using 3D / courtyard / real mechanical evidence |

## Applicable Altium Rule Baseline

The active Altium DRC configuration shown in the latest user-provided report is the current Stage 6 working rule baseline. Manufacturing limits are not automatically adopted as design targets.

| Rule / intent | Current value | Scope / note |
| --- | --- | --- |
| Default electrical clearance | **6 mil** | whole-board default |
| `GND_IN_RAW` ↔ `GND` clearance | **20 mil** | explicit higher-priority exception |
| Default routing width | **6 / 6 / 15 mil** | min / preferred / max |
| `SW_NODE` width | **16 / 20 / 24 mil** | min / preferred / max |
| `NC_POWER` width | **8 / 20 / 32 mil** | min / preferred / max |
| `NC_POWER` Net Class | `24V_IN_RAW`, `24V_PROTECTED`, `3V3`, `USB_VBUS`, `GND_IN_RAW` | `VDDA`, `GND`, `USB_GND` are not members |
| Typical power routing | 20 mil | preferred where local copper is not more appropriate; 8 mil is accepted as the configured local minimum |
| Default routing via | 0.60 mm diameter / 0.30 mm drill | whole-board default routing via |
| USB pair geometry | width 8 mil / gap 8 mil / max uncoupled 200 mil | routing guidance only; no controlled-impedance claim |
| Power-plane / relief connect | 4 entries, 10 mil conductor, 10 mil air gap, 20 mil expansion | current DRC-reported connection rule |
| Polygon connect intent | SMD Direct; Via Direct; preserve intentional THT relief and all domain boundaries | implementation must not bridge isolated nets |
| Solder Mask Expansion | **2 mil** | ordinary pads should use `Solder -> Rule Expansion`; imported fixed/manual pad shapes must not silently override the project rule |
| Paste Mask Expansion | **0 mil, Absolute** | ordinary SMD pads: Paste enabled and `Paste -> Rule Expansion`; TH pads: Top/Bottom Paste disabled |
| Hole size | **10–240 mil** | applicable drilled holes |
| Hole-to-hole clearance | **8 mil** | keep at 8 mil for current project baseline |
| Minimum solder-mask sliver | **6 mil** | current DRC baseline; latest report has 0 violations |
| Silk-to-solder-mask clearance | **6 mil** | documentation / manufacturability cleanup item when violated |
| Silk-to-silk clearance | **6 mil** | documentation / legibility cleanup item; not an electrical blocker by itself |
| Net Antennae tolerance | **0 mil** | retain checker; intentional HSE GND guard branches are explicitly dispositioned in `docs/pcb_review.md` |
| PTH minimum annular ring | 10 mil | applicable plated holes |
| Board-outline clearance | 12 mil | applicable copper / object clearance |
| Component clearance | 20 mil | component-to-component baseline |

## Solder / Paste Mask Baseline and Imported-Library Guardrails

The current `.PcbDoc` has been reviewed after a systematic mask-property issue was found in several footprints imported from JLCPCB / EasyEDA into Altium.

### Ordinary solder-mask behavior

- Ordinary solderable pads should use `Solder -> Rule Expansion` rather than a fixed per-pad solder-mask shape.
- The project working `Solder Mask Expansion` baseline is **2 mil**.
- A fixed imported solder-mask shape (for example an unrelated 68 mil manual shape) is not equivalent to following the project rule and must be normalized when found.

### Ordinary paste-mask behavior

- The project working `Paste Mask Expansion` baseline is **Absolute, 0 mil**.
- Ordinary SMD pads should have Paste enabled and use `Paste -> Rule Expansion`.
- Ordinary through-hole pads must not receive Top or Bottom Paste openings.
- `Rule Expansion + 0 mil` means an effective paste aperture based on the copper pad with zero expansion. It is **not** equivalent to an imported manual `Round/Rectangular/Custom` paste shape whose X/Y dimensions are `0 × 0 mil`; the latter can produce no usable stencil aperture.
- Pad-level manual/shape overrides must therefore be reviewed before assuming that the board rule is actually controlling the output.

### Special-pad exception

Thermal / exposed / power pads, large power-MOSFET lands, and manufacturer-defined stencil apertures may require dedicated review rather than blind normalization with ordinary SMD pads. Current examples are U2 `LMR36510FADDAR` and Q25 `DMT10H015LFG-13 / PowerDI3333-8`. Their electrical net mapping and final paste output must remain consistent with the active `.PcbDoc` and manufacturer/package guidance.

### Library root cause and recurrence prevention

- The current PCB-side systematic `Round 0 × 0 mil` Paste issue has been corrected by returning ordinary SMT pads to `Paste -> Rule Expansion`.
- Equivalent ordinary-pad cleanup should also be preserved in the source `PCB1.PcbLib`; otherwise a later footprint re-placement or library update can reintroduce fixed mask properties into the PCB.
- Do not update a nearly finished routed PCB from an imported footprint library merely to clean mask metadata unless the footprint delta has been reviewed; direct `.PcbDoc` pad normalization and separate `.PcbLib` cleanup are safer for the current revision.
- Final manufacturing authority remains the generated Paste / Gerber output, not the library-editor preview alone.

## Implemented Stage 6 Layer / Copper Strategy

```text
Top:
- primary GPIO / local signals
- local power and critical loops
- broad machine-side GND polygon where useful
- USB-domain Top USB_GND copper in the isolated USB region
- HSE signal routing and local GND guard with dedicated Top cutout

Bottom:
- machine-side GND reference plane as the dominant use
- isolated USB-domain USB_GND polygon
- limited regional 3V3 trunks
- only necessary short GPIO / SWD / NRST crossovers
```

Do not reroute already-accepted regions merely to force every signal onto Top. Conversely, do not expand Bottom signal usage if it unnecessarily fragments the GND plane.

## Routing-Driven GPIO Baseline

```text
IN11 -> PA8
IN12 -> PA11
IN13 -> PA12
IN14 -> PA15
IN15 -> PB4
IN16 -> PB5
IN17 -> PB6
IN18 -> PB7

SENSOR2_NO -> PA0
SENSOR2_NC -> PA1
OUT1 -> PA2
OUT2 -> PA3
OUT3 -> PA4
OUT4 -> PA5
OUT5 -> PA6
OUT6 -> PA7
OUT7 -> PB10
OUT8 -> PB11
SENSOR1_NO -> PB8
SENSOR1_NC -> PB9
SENSOR3_NO -> PB12
SENSOR3_NC -> PB13
SENSOR4_NO -> PB14
SENSOR4_NC -> PB15
```

These are now PCB routing facts. Reopening them requires final-review evidence of a real electrical / DRC / routing defect.

## USB / Isolation Copper Baseline

- USB D+/D- and USB_VBUS routing are complete at screenshot level and should remain frozen unless final review finds a defect.
- The isolated USB area uses **Bottom USB_GND polygon** as its primary reference/return copper.
- A **Top USB_GND polygon/copper area is now implemented** in the USB domain to improve local return connectivity; this supersedes the earlier note that no broad Top USB_GND copper had been added.
- Top and Bottom USB-domain copper remain confined to the USB side of the ISO7721 boundary.
- USB-domain GND pads connect locally by short copper / vias into the Top/Bottom USB_GND structure.
- ISO7721 is the boundary between `USB_VBUS / USB_GND` and `3V3 / GND`.
- **Top and Bottom polygon-pour cutouts / copper exclusion remain through the ISO7721 isolation region.** No via is intentionally placed inside the isolation corridor.
- `USB_GND` stitching vias may be used inside the USB domain; machine `GND` vias remain on the machine side. No cross-boundary via fence is required.
- `IN11 -> PA8` is retained; the isolation-area conflict is solved by a short Bottom crossover that stays machine-side and outside the ISO7721 exclusion region.

## Buck Ground / Switching Baseline

- U2 exposed pad uses multiple GND / thermal vias.
- C11/C12 input-capacitor GND is implemented as a compact local Top GND copper connection with multiple vias into the Bottom GND plane.
- C14/C15/C16 output-capacitor GND uses broad local GND copper and multiple vias.
- Preserve the compact C11/C12 -> U2 VIN/PGND high-current input loop.
- `SW_NODE` must remain local; do not expand the switch-node copper during cosmetic cleanup.
- R37/R42 FB routing is a small-signal path and must remain away from `SW_NODE`.
- Final copper review must explicitly prove `GND_IN_RAW` does not bypass Q25.

## HSE Crystal Baseline

- X1/C2/C4 placement is frozen unless DRC or electrical review identifies a real problem.
- OSC traces remain short, local, Top-layer and without intentional vias.
- X1 GND/case pads and C2/C4 GND pads use local GND vias.
- Top uses a **10 mil GND guard track** around the local oscillator region.
- Guard/local-ground vias connect the oscillator GND structure into Bottom GND.
- A **Top Polygon Pour Cutout** excludes the oscillator zone from broad Top GND fill so the guard structure remains explicit.
- Bottom under/around the oscillator is reserved as a quiet local GND return/shield area; unrelated GPIO, SWD, UART, NRST, 3V3 trunks or other crossovers must not traverse it.
- The latest DRC reports six `Net Antennae` findings in this area. User-provided object-level screenshot evidence confirms they are the intentional GND guard tracks / GND stitching vias, not unassigned copper or unrouted signal stubs. They are accepted review findings; an Altium waiver object is not claimed unless separately created.

## Debug Routing Baseline

- SWDIO, SWCLK and MCU_NRST use Bottom routing where required by crossing topology.
- The NRST Bottom segment may pass under the projection of MCU pin 39 because the MCU pad is a Top SMD object; actual clearances are now covered by the executed DRC.
- SWDIO / SWCLK do not require differential or length-matching rules.

## Whole-Board GND / Polygon Baseline

Machine-side GND-via stitching is now substantially complete at screenshot level. USB-domain stitching has also been added without bridging the isolation boundary.

Before Stage 6 closeout, final repour/review must still confirm:

- Bottom machine `GND` remains broadly continuous despite Bottom 3V3 trunks and short crossovers.
- No disconnected / orphan copper islands remain.
- No narrow GND neck is created around MCU fanout or long parallel Bottom traces.
- `USB_GND` and machine `GND` remain isolated.
- `GND_IN_RAW` and machine `GND` remain separated except through Q25 as designed.
- HSE Bottom GND remains quiet and free of unrelated signal crossings.
- Buck, MCU decoupling, VDDA, SWD/UART and connector return paths remain sensible after final repour.
- M3 mounting-hole keepouts remain free of unintended copper / vias / tracks.

## Latest DRC Evidence — 2026-09-03 20:33

Latest user-provided Altium Design Rule Verification Report:

```text
Warnings: 0
Rule Violations: 29

Electrical / connectivity blockers:
Short-Circuit: 0
Un-Routed Net: 0
Default Width: 0
SW_NODE Width: 0
NC_POWER Width: 0
GND_IN_RAW <-> GND 20 mil Clearance: 0
Hole Size: 0
Hole-to-Hole: 0
Minimum Solder Mask Sliver: 0
Modified Polygon: 0
```

Remaining 29 findings are currently dispositioned as:

- **4 × Clearance**: each M3 NPTH `Free-2` pad intersects its own intentionally centered solid Keepout Region. This is an intentional mounting-hole geometry / rule-scope collision, not evidence of copper entering the keepout. Preserve the M3 hole and keepout; handle with targeted exception / waiver if a clean numeric DRC is required.
- **2 × Silk-to-Solder-Mask**: Q12 top-overlay geometry is too close to the pad solder-mask opening. Non-electrical cleanup; easy to correct and recommended before manufacturing output.
- **17 × Silk-to-Silk**: reference-designator / footprint-silkscreen spacing. Non-electrical legibility cleanup; do not move components merely to clear these.
- **6 × Net Antennae**: confirmed intentional HSE GND guard tracks / GND vias. Preserve the guard structure; treat as accepted intentional findings or targeted waiver.

Therefore, **no currently reported violation represents a confirmed electrical routing/connectivity blocker**, but a formal DRC PASS is not claimed while the report still contains 29 findings.

## Stage 6 Final Review / Closeout Requirements

Stage 6 is **not yet closed**. The next activity is final PCB review and DRC disposition, not more routine routing.

Required evidence before any closeout / manufacturing transition:

1. No unintended unrouted nets or incomplete connections — latest DRC currently shows 0.
2. Full-board Top / Bottom routing review.
3. Final Bottom `GND` and `USB_GND` polygon continuity / island / narrow-neck review.
4. `USB_GND != GND` verification across ISO7721 after final repour.
5. `GND_IN_RAW != GND` / Q25 non-bypass verification.
6. Buck critical-loop / `SW_NODE` / FB review.
7. HSE guard / return / no-crossing review; preserve intentional guard antennae findings.
8. MCU decoupling / VDDA / NRST / SWD return review.
9. Board-edge / M3 keepout / connector mechanical review.
10. Final disposition of the 4 intentional M3 self-keepout collisions, 6 intentional HSE antennae findings, and remaining silkscreen cleanup findings.
11. Preserve the closed `.PcbDoc` Solder/Paste mask normalization and recheck final `GTP/GBP` or equivalent manufacturing Paste output before release.

## Current Conclusion

**Stage 5 Placement remains PASS / CLOSED. Stage 6 routing, polygons and GND-via implementation are complete at user/screenshot level. DRC has been executed and no electrical blocker remains in the latest report, but formal DRC PASS, final routed-copper PASS and manufacturing release remain pending until final whole-board review and disposition of the remaining intentional / silkscreen findings.**

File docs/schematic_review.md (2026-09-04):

# Schematic Review

Review Status: **PASS / CLOSED — POST-REVIEW CORRECTIVE DELTAS RECORDED**

Final Stage 4 review conclusion remains: **可以进入 PCB Layout**. Stage 4 Formal Schematic Review is historically closed. During Stage 6 final PCB review, two schematic implementation defects were identified, corrected by the user in Altium, and visually re-reviewed on 2026-09-04. These later corrections are recorded below without claiming a new full-board ERC or complete Stage 4 rerun.

## Evidence Boundary

- Stage 4 closeout evidence remains the archived complete schematic PDF and BOM in `hardware/outputs/`.
- 2026-09-04 corrective evidence consists of user-provided current Altium schematic screenshots showing the corrected U2 LMR36510 EN/PG connections and corrected U3 CH340C TXD/RXD net mapping.
- User confirmation that Q25 schematic symbol D/G/S ↔ PowerDI3333-8 footprint pads ↔ manufacturer pinout was finally checked in Altium.
- Evidence boundary: no ERC claim, no hardware-test claim, no EMC/surge compliance claim, and no `.SchDoc` parser claim. The targeted corrective checks do not assert a broader full-board footprint-mapping or schematic PASS beyond the documented review scope.

## Findings

| ID | Module | Finding / disposition | Risk | Status | Evidence / remaining check |
| --- | --- | --- | --- | --- | --- |
| SR-M1-001 | M1 reverse-polarity protection | Positive path is `24V_IN_RAW -> F1 -> D9 STPS2H100A -> 24V_PROTECTED`. Negative path is `GND_IN_RAW -> Q25 DMT10H015LFG-13 -> PCB GND`; R65 10 kΩ connects `24V_IN_RAW` to Gate, R66 100 kΩ connects Gate to Source / PCB GND, and D12 `MMSZ5242B-7-F` has Cathode at Gate and Anode at Source / PCB GND. `GND_IN_RAW` must remain isolated from PCB `GND` except through Q25. | High | **CLOSED** | User completed the final Q25 D/G/S ↔ PowerDI3333-8 pads ↔ manufacturer pinout check in Altium. |
| SR-M1-002 | M1 buck output capacitors | C14/C15/C16 are Samsung `CL31B226KPHNNNE`, LCSC `C87996`, 22 uF, 10 V, X7R, 1206. | Medium | **CLOSED** | Current BOM and module records synchronized. |
| SR-M1-003 | M1 LMR36510 control pins | Stage 6 review found U2 `EN` and `PG` previously floating in the current schematic implementation. The user corrected `EN -> 24V_PROTECTED` and unused `PG -> GND`. | High | **CLOSED — CORRECTED 2026-09-04** | Current Altium screenshot evidence visually confirms both corrected connections. No ERC PASS is claimed. |
| SR-M3-001 | M3 CH340C ↔ ISO7721 UART direction | Stage 6 review found the CH340C TXD/RXD net names reversed at U3, which would have produced output-to-output / input-to-input pairing against the ISO7721 channel directions. The user corrected `U3 pin 2 TXD -> CH340_TX` and `U3 pin 3 RXD <- CH340_RX`, preserving the already-correct ISO7721 side mapping. | High | **CLOSED — CORRECTED 2026-09-04** | Current Altium screenshot evidence confirms the U3 correction. The intended path is `CH340 TXD -> ISO7721 INB -> OUTB -> MCU RX` and `MCU TX -> ISO7721 INA -> OUTA -> CH340 RXD`. No ERC or hardware UART test is claimed. |
| SR-M45-001 | M4/M5 2N7002 | LCSC `C7420321` is intentionally retained from the previous working board and is accepted for the present low-current level-translation application. Earlier Nexperia `2N7002,215` qualification remains useful reference history, not a mandatory replacement requirement. | Low | **ACCEPTED / DOCUMENTATION SYNCED** | Project decision and previous-board working evidence; normal purchase-time identity and footprint checks still apply. |

## Closed Q25 Mapping Record

The user completed the final Altium check that the Q25 schematic symbol Drain/Gate/Source mapping agrees with the selected PowerDI3333-8 footprint pads and manufacturer pinout. SR-M1-001 is closed. PCB implementation must preserve this mapping, and no copper, port, harness definition, or footprint connection may bypass Q25 from `GND_IN_RAW` into PCB `GND`.

## Post-Review Corrective Delta — 2026-09-04

Two targeted corrections were made after the historical Stage 4 closeout:

```text
M1 / U2 LMR36510
EN -> 24V_PROTECTED
PG -> GND (unused PG; not left floating)

M3 / U3 CH340C
TXD -> CH340_TX
RXD <- CH340_RX

ISO7721 direction retained:
CH340_TX -> INB -> OUTB -> MCU_UART_RX
MCU_UART_TX -> INA -> OUTA -> CH340_RX
```

These corrections were made before final PCB manufacturing preparation and were propagated into the PCB connectivity by the user. They remove the two functional blockers identified during Stage 6 review. Because the review evidence is targeted screenshot evidence rather than a complete exported ERC report, the repository still does not claim full ERC PASS.

## Conclusion

Stage 4 Formal Schematic Review remains **PASS / CLOSED** as the historical gate, with the 2026-09-04 post-review corrective deltas now explicitly documented and closed. The current engineering review has no known remaining schematic blocker from these two findings. No ERC PASS, broader full-board footprint-mapping PASS, hardware-test PASS, USB/UART functional-test PASS, or EMC/surge compliance PASS is recorded; no `.SchDoc` parser claim is made.

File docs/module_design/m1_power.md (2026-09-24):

# M1 — 24 V Input / Protection / 3.3 V Power

## Module Status and Boundary

- Responsibility: accept machine 24 V, provide overcurrent and reverse-polarity protection, establish `24V_PROTECTED`, suppress transients, and generate the machine-side `3V3` rail.
- Current M1 schematic / PCB implementation disposition: **CLOSED at design-review level**. The user completed the final Q25 schematic-symbol D/G/S ↔ PowerDI3333-8 footprint-pad ↔ manufacturer-pinout check in Altium; SR-M1-001 is closed.
- A Stage 6 corrective review on 2026-09-04 also confirmed the LMR36510 enable / power-good handling: `EN` is tied to `24V_PROTECTED`, and unused `PG` is tied to `GND` rather than left floating.
- Stage 4 Formal Schematic Review remains **PASS / CLOSED** as the historical gate; the later corrective delta is documented here and in `docs/schematic_review.md`.
- Actual hardware bring-up has since included 24 V board power and a practical check of the 3.3 V test point before ST-Link connection. See [`docs/bringup_log.md`](../bringup_log.md). This does not add an exact voltage, input-current, ripple, startup, load, thermal, abnormal-supply, surge, or EMC result and is not a complete power-stage PASS.

## Structured Connection Facts

```text
P1 WJ500V-5.08-2P positive input -> 24V_IN_RAW
P1 WJ500V-5.08-2P negative input -> GND_IN_RAW
24V_IN_RAW -> F1 0468.500NRHF -> D9 STPS2H100A anode
D9 cathode -> 24V_PROTECTED
Q25 DMT10H015LFG-13 Drain -> GND_IN_RAW
Q25 Source -> PCB GND
R65 10 kohm: 24V_IN_RAW -> Q25 Gate
R66 100 kohm: Q25 Gate -> Q25 Source / PCB GND
D12 MMSZ5242B-7-F cathode -> Q25 Gate
D12 anode -> Q25 Source / PCB GND
D10 SMBJ30A-TR cathode -> 24V_PROTECTED
D10 anode -> GND

U2 LMR36510FADDAR PGND / EP -> GND
U2 VIN / EN -> 24V_PROTECTED
U2 PG -> GND (unused PG; do not leave floating)
C11 2.2 uF / 100 V / X7R: 24V_PROTECTED <-> GND
C12 220 nF / 100 V / X7R: 24V_PROTECTED <-> GND
C13 1 uF / X7R / >=16 V: U2 VCC <-> GND
U2 BOOT capacitor -> SW_NODE
U2 SW -> SW_NODE -> L1 SWPA6045S220MT -> 3V3
3V3 -> R37 100 kohm / 1% -> U2 FB -> R42 43.2 kohm / 1% -> GND
C14 / C15 / C16, each Samsung CL31B226KPHNNNE / LCSC C87996 / 22 uF / 10 V / X7R / 1206: 3V3 <-> GND
```

P1 is the current capture choice, not final enclosure/mechanical approval. No additional mandatory large input bulk capacitor is fitted or selected; a possible future DNP footprint is not part of the present baseline.

## Key Parameter Decisions

- Output target: 3.3 V. The `100 kΩ / 43.2 kΩ` divider is the current 1% baseline.
- L1 is frozen as Sunlord `SWPA6045S220MT`, LCSC `C83454`, 22 µH ±20%, shielded SMD power inductor, approximately 6 × 6 × 4.5 mm.
- Sunlord official SWPA data lists DCR 116 mΩ max / 89 mΩ typ, saturation current 2.05 A min / 2.20 A typ, and heat-rating current 1.80 A max / 2.00 A typ. Manufacturer data is the electrical authority; LCSC is procurement evidence.
- C14/C15/C16 are frozen as Samsung `CL31B226KPHNNNE`, LCSC `C87996`, 22 uF, 10 V, X7R, 1206. Effective capacitance under DC bias remains a validation item.

## Engineering Basis and Interfaces

- The accepted protection architecture keeps `24V_IN_RAW -> F1 -> STPS2H100A -> 24V_PROTECTED` on the positive rail and inserts Q25 in the negative return between `GND_IN_RAW` and PCB `GND`.
- R65 turns Q25 on for correct polarity, R66 provides gate-source bias, and D12 is the Q25 gate-source clamp. `GND_IN_RAW` is not PCB `GND` and must not bypass Q25.
- `EN` tied to `24V_PROTECTED` establishes always-on behavior when protected input power is present. `PG` is unused and is tied to `GND` in the corrected current schematic rather than left floating.
- Outputs are `24V_PROTECTED` for field/interface loads and `3V3` for M2 and machine-side logic.
- Follow TI placement guidance during layout: minimize the VIN/PGND input loop, SW/BOOT loop, and output switching-current loop; keep FB sensing away from `SW_NODE`.

## Stage 6 PCB Status

- M1 placement and routing are implemented in the current `.PcbDoc`; the power-stage layout is no longer in a pre-layout state.
- U2 exposed-pad / GND thermal vias are retained.
- C11/C12 input-capacitor GND uses compact local Top GND copper with multiple GND vias; C14/C15/C16 output return uses broad local GND / multiple vias.
- `SW_NODE` remains local and the current DRC width rule reports no violation.
- `GND_IN_RAW -> Q25 -> GND` remains a locked functional boundary; the dedicated 20 mil `GND_IN_RAW` ↔ `GND` DRC rule reports 0 violation in the latest reviewed DRC.
- Final Gerber/CAM manufacturing interpretation and board manufacture occurred after this design closeout; neither event by itself proves startup, power integrity, or protection performance.

## Remaining Validation

- Full-board startup/inrush, quantified steady-state input current, and F1 time-current coordination are unmeasured.
- C14/C15/C16 effective capacitance under DC bias, diode/MOSFET loss, ripple, and thermal behavior remain to be checked as applicable.
- Preserve the user-verified Q25 D/G/S ↔ PowerDI3333-8 pad ↔ manufacturer-pinout mapping during any later PCB edit; `GND_IN_RAW` must not bypass Q25 into PCB `GND`.
- The released assembly has powered and its 3.3 V rail has been checked at a basic functional level; quantified startup behavior, measured power integrity, load behavior, and abnormal-input behavior remain pending.
- No source-impedance, surge-waveform, IEC, or other compliance result is claimed.

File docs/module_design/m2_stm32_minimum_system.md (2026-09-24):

# M2 — STM32F103C8T6 Minimum System

## Module Status and Boundary

- Responsibility: STM32F103C8T6 LQFP48 power, clock, reset, boot, SWD, USART1, board-level GPIO allocation, and startup interface contract.
- Stage 3 module conclusion remains **CLOSEOUT ACCEPTABLE**; Stage 4 Formal Schematic Review is **PASS / CLOSED** and PCB Layout entry is approved.
- Actual hardware bring-up has since included a 3.3 V check, ST-Link connection, STM32 firmware programming, and basic runtime/host communication. See [`docs/bringup_log.md`](../bringup_log.md). Firmware identity, programming log, reset/BOOT coverage, quantified timing, long-duration operation, EMC, and surge behavior were not provided and are not claimed PASS.

## Power, Clock, Reset, and Boot

```text
VDD_1 / VDD_2 / VDD_3 -> 3V3; each VDD has 100 nF local decoupling to GND
3V3 -> 10 uF MCU rail bulk -> GND
3V3 -> R19 0 ohm -> VDDA
VDDA -> 100 nF + 1 uF local decoupling -> GND
VSS_1 / VSS_2 / VSS_3 / VSSA -> GND
3V3 -> VBAT; VBAT -> 100 nF -> GND

PD0 / OSC_IN <-> TKD SX32Y008000BC1T001 8 MHz SMD3225 CL=12 pF
crystal <-> R6 0 ohm <-> PD1 / OSC_OUT
each crystal side -> 15 pF C0G/NP0 -> GND

NRST -> 100 nF -> GND
NRST -> manual normally-open reset switch -> GND
NRST -> SWD NRST
BOOT0 -> 10 kohm -> GND; service jumper/header may pull BOOT0 to 3V3
PB2 / BOOT1 -> R28 10 kohm -> GND
```

- R19 is the fitted 0 Ω VDDA-link baseline and preserves later filtering flexibility; no ferrite bead is currently fitted.
- No separate RTC battery and no LSE are fitted. The reset network has no external NRST pull-up.
- R6 is fitted at 0 Ω and retained as the HSE crystal series/damping tuning provision.
- Normal boot is BOOT0 LOW + BOOT1 LOW/default -> Main Flash. Reset-switch and service-header mechanical MPNs are not frozen and do not block current module closeout.

## SWD and USART1

```text
PA13 -> SWDIO
PA14 -> SWCLK
SWD 1x5 -> VTREF / 3V3, SWDIO, SWCLK, GND, NRST
PA9  -> MCU_UART_TX -> later ISO7721DR / CH340C path
PA10 <- MCU_UART_RX <- later ISO7721DR / CH340C path
```

`VTREF / 3V3` is primarily a target-voltage reference. The interface is not documented as a default means for ST-Link to power the complete 24 V industrial board. Final header MPN/mechanics remain open.

## Board-level GPIO Allocation

| Function | STM32 pins |
| --- | --- |
| CM35 status sense | OUT1→PA2, OUT2→PA3, OUT3→PA4, OUT4→PA5, OUT5→PA6, OUT6→PA7, OUT7→PB10, OUT8→PB11 |
| Sensor inputs | SENSOR1_NO→PB8, SENSOR1_NC→PB9, SENSOR2_NO→PA0, SENSOR2_NC→PA1, SENSOR3_NO→PB12, SENSOR3_NC→PB13, SENSOR4_NO→PB14, SENSOR4_NC→PB15 |
| CM35 controls | IN11→PA8, IN12→PA11, IN13→PA12, IN14→PA15, IN15→PB4, IN16→PB5, IN17→PB6, IN18→PB7 |
| Debug | PA13 SWDIO, PA14 SWCLK |
| HSE | PD0 OSC_IN, PD1 OSC_OUT |
| Reserved / spare  | PB0/PB1 spare; PB2 BOOT1; PB3 spare/SWO; PC13 spare; PC14/PC15 spare with LSE unused |

This table is the locked Stage 6 routing-driven GPIO baseline from `README.md` and `docs/pcb_review.md` and supersedes the earlier placement-era allocation. PA15/PB3/PB4 are SWJ/JTAG-related at reset; firmware must release the relevant JTAG resources before using PA15 and PB4 as ordinary GPIO while retaining the required SWD access.

## Cross-module Safe-startup Contract

M2 does not rely on MCU reset GPIO state alone to guarantee CM35 inactivity. M4 must implement:

```text
MCU GPIO high-Z -> 3.3 V-side pull-up -> 2N7002 OFF
-> 24 V side HIGH -> CM35 input inactive
```

This is the implemented cross-module design contract, not a claim that reset, initialization, brownout, and power-down behavior have all been measured on every output.

## Remaining Validation

- The current record is based on user-reported/reviewed EDA capture and engineering decisions; the `.SchDoc` was not parsed or modified by Codex.
- Final reset switch and SWD header mechanical selections remain open.
- Programming and basic operation have been performed, but complete reset/BOOT coverage, GPIO startup-state measurements, long-duration runtime, and a firmware-to-final-mapping audit remain to be recorded.

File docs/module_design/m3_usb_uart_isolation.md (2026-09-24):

# M3 — USB-C / CH340C / Isolated UART

## Module Status and Boundary

- Responsibility: provide the PC USB device interface, USB data-line ESD protection, USB-to-UART conversion, and galvanically isolated bidirectional UART connection to STM32 USART1.
- Stage 3 module conclusion remains **CLOSEOUT ACCEPTABLE**; Stage 4 Formal Schematic Review is **PASS / CLOSED** and PCB Layout entry is approved.
- Actual hardware bring-up has since included host serial communication and basic functional debugging. See [`docs/bringup_log.md`](../bringup_log.md). The supplied evidence does not include enumeration details, a bidirectional error-rate/duration record, every power sequence, measured isolation performance, isolation withstand, EMC/ESD, or a complete hardware-test PASS.

## Power Domains and Structured Connection Facts

```text
USB domain: USB_VBUS / USB_GND
Machine domain: 3V3 / GND
Hard boundary: USB_GND != GND
```

### USB-C receptacle — TYPE-C-31-M-12

```text
A1/B12 + B1/A12 GND -> USB_GND
A4/B9 + B4/A9 VBUS -> USB_VBUS
A5 CC1 -> R53 5.1 kohm / 1% -> USB_GND
B5 CC2 -> R57 5.1 kohm / 1% -> USB_GND
A6 DP1 + B6 DP2 -> USB_DP_RAW
A7 DN1 + B7 DN2 -> USB_DM_RAW
A8 SBU1 -> NC
B8 SBU2 -> NC
EH / shield pins -> USB_GND (current baseline)
```

The current receptacle remains mechanically conditional until board-edge, enclosure, and cable-access constraints are frozen. No chassis/PE domain is currently defined, so the shield baseline is direct connection to `USB_GND`; an RC shield network is not part of the present design.

### USBLC6-2SC6

```text
pin 1 I/O1 -> USB_DP_RAW
pin 6 I/O1 -> USB_DP -> CH340C pin 5 D+
pin 3 I/O2 -> USB_DM_RAW
pin 4 I/O2 -> USB_DM -> CH340C pin 6 D-
pin 2 GND -> USB_GND
pin 5 VBUS -> USB_VBUS
C18 100 nF X7R: USB_VBUS <-> USB_GND
```

### CH340C

```text
pin 1 GND -> USB_GND
pin 16 VCC -> USB_VBUS
C19 100 nF X7R: USB_VBUS <-> USB_GND
pin 4 V3 -> C20 100 nF X7R -> USB_GND
pin 5 D+ -> USB_DP
pin 6 D- -> USB_DM
pin 2 TXD -> CH340_TX
pin 3 RXD <- CH340_RX
pin 7 NC -> NC
pin 8 OUT# -> NC
pins 9-14 modem/status signals -> NC
pin 15 R232 -> NC
```

CH340C uses its internal clock; no external crystal is fitted. The present baseline does not add external USB D+/D- series resistors or UART pull resistors.

### ISO7721DR

```text
USB side:
pin 1 VCC1 -> USB_VBUS
pin 4 GND1 -> USB_GND
C21 100 nF X7R: VCC1 <-> GND1

Machine side:
pin 8 VCC2 -> 3V3
pin 5 GND2 -> GND
C22 100 nF X7R: VCC2 <-> GND2

PC -> MCU direction:
CH340C TXD -> CH340_TX -> pin 3 INB
pin 6 OUTB -> MCU_UART_RX -> STM32 PA10

MCU -> PC direction:
STM32 PA9 -> MCU_UART_TX -> pin 7 INA
pin 2 OUTA -> CH340_RX -> CH340C RXD
```

The isolator is powered independently on both sides: `USB_VBUS / USB_GND` on side 1 and `3V3 / GND` on side 2. No isolated DC/DC is required solely for M3 because the two sides already have independent power sources.

## Startup, Idle, and Power-off Behavior

- UART idle is HIGH. The selected non-F ISO7721 variant has a default-HIGH output behavior when the corresponding input side is unavailable, which is compatible with the UART idle requirement.
- With USB unplugged while machine-side `3V3` remains powered, the machine-side UART receive path is intended to remain at the inactive/HIGH state rather than create a false start bit.
- With machine-side power removed while USB remains present, the USB-side UART receive path is likewise intended to remain inactive/HIGH.
- Each active transmitter and its local ISO7721 supply side share the same local power domain in normal operation: CH340C with `USB_VBUS`, STM32 with `3V3`. This avoids the ordinary operating case of a powered UART transmitter directly driving an unpowered isolator input-side supply domain.
- These are schematic-level design conclusions; actual plug/unplug, brownout, enumeration, and powered/unpowered behavior remain to be verified on hardware.

## Engineering Basis and Layout-sensitive Constraints

- `USB_GND` and machine `GND` must remain electrically separate across the ISO7721 barrier. No wire, copper pour, test point, mounting feature, shield connection, or other net may unintentionally bridge them.
- Place USBLC6-2SC6 close to the USB-C receptacle and keep the ESD current return to `USB_GND` short. Route D+/D- through the protection device without long stubs.
- Keep CH340C VCC/V3 bypass capacitors close to their corresponding pins.
- Keep C21 and C22 close to the ISO7721 VCC/GND pin pairs on their respective sides.
- Preserve the isolator package creepage/clearance region in PCB implementation; the Project does not currently claim a specific reinforced-safety, mains-isolation, or system compliance rating.
- Direct shield-to-`USB_GND` termination is the present baseline. Revisit only if a chassis/PE domain is introduced or later EMC/ESD evidence justifies a different termination network.

## Remaining Validation

- USB-C receptacle mechanical/enclosure qualification remains open.
- Basic host communication has been exercised; detailed enumeration evidence, sustained/error-counted UART testing, unplug/replug recovery, and simultaneous/independent domain power sequencing remain to be recorded.
- ERC, complete pin/footprint mapping against exported schematic evidence, PCB isolation geometry, signal integrity, EMC/ESD, and system-level isolation compliance remain unverified.
- A normal non-isolated ST-Link can connect the host-computer ground to PCB `GND`. When the computer or grounded instruments also touch the USB domain, this can create an external `USB_GND` ↔ PCB `GND` path and defeat the intended isolation. Isolation-related tests must account for or remove this path; basic UART success does not prove isolation integrity.

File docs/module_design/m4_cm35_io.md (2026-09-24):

# M4 — CM35 Industrial I/O Interface

## Module Status and Boundary

- Responsibility: provide 8 STM32 → CM35 IN11–IN18 control channels and 8 CM35 OUT1–OUT8 → STM32 status channels.
- Stage 3 module conclusion remains **CLOSEOUT ACCEPTABLE**; Stage 4 Formal Schematic Review is **PASS / CLOSED** and PCB Layout entry is approved.
- Stage 5 full-board Placement has now been reviewed from the user-provided Altium placement / Ratsnest evidence and is **PASS / CLOSED**; Stage 6 Routing and Copper may proceed.
- Actual hardware bring-up has since included host-commanded industrial I/O debugging and corresponding motion-controller input-terminal voltage checks. Approximate inactive/active behavior of 24 V/0 V was observed for the Active-Low interface. See [`docs/bringup_log.md`](../bringup_log.md). The tested channel subset was not supplied, so this is not a channel-by-channel CN5/CN6 PASS or an EMC/surge result.

## Power-domain Decision

Rev.A separates the CM35 controller system supply from the isolated I/O supply, following the user-provided CM35 official-manual evidence:

```text
CM35 system domain
  PSU A +24 V -> CM35 24V
  PSU A -V    -> CM35 0V

Isolated I/O domain
  PSU B +24 V -> CM35 V
  PSU B -V    -> CM35 G / 24G
  PSU B +24 V -> P1 -> 24V_IN_RAW -> protection -> 24V_PROTECTED
  PSU B -V    -> P1 -> GND_IN_RAW -> Q25 -> PCB GND
```

Therefore `PCB GND = CM35 G / 24G = PSU B -V`. This node **MUST NOT** be directly connected to CM35 system `0V`, PSU A `-V`, PE, or chassis; `PSU A -V != PSU B -V`. The exact PSU-B model, manufacturer, and current rating remain a later procurement/system-integration decision.

CM35 `V/G` receives cabinet-distributed PSU-B power directly at the terminal distribution. It is not powered from the PCB and must not be routed through PCB F1 or exported from `24V_PROTECTED`. The PCB branch remains `PSU B +24 V -> M1 -> F1 -> reverse-polarity protection -> 24V_PROTECTED` for M4 pull-ups, M5 sensors, and LMR36510-derived `3V3`.

The existing 16-channel 2N7002 circuit, GPIO mapping, Active-Low behavior, and safe-startup contract remain unchanged and **CLOSEOUT ACCEPTABLE**. Rev.A does not add 16-channel optocouplers, per-channel digital isolation, a PCB isolated DC/DC, or a new CM35 `V/G` power-output connector because the PCB and CM35 I/O belong to the same isolated PSU-B I/O domain.

## Repeated Channel Topology

All 16 channels retain the current 2N7002 device, LCSC `C7420321`. Nexperia `2N7002,215` remains qualification history/reference and is not the current mandatory Primary replacement. Each channel follows the same level-translation structure:

```text
3V3 -> 10 kohm -> MCU-side node -> 2N7002 Source
3V3 ----------------------------> 2N7002 Gate
24V_PROTECTED -> 10 kohm -> CM35-side node -> 2N7002 Drain
```

No default RC filtering capacitor is fitted in M4. The present installation evidence does not justify adding per-channel RC filtering to the CM35 cabinet wiring.

### STM32 → CM35 controls

| CM35 input | STM32 GPIO | Physical behavior |
| --- | --- | --- |
| IN11 | PA8 | GPIO LOW = Active; GPIO HIGH = Inactive |
| IN12 | PA11 | GPIO LOW = Active; GPIO HIGH = Inactive |
| IN13 | PA12 | GPIO LOW = Active; GPIO HIGH = Inactive |
| IN14 | PA15 | GPIO LOW = Active; GPIO HIGH = Inactive |
| IN15 | PB4 | GPIO LOW = Active; GPIO HIGH = Inactive |
| IN16 | PB5 | GPIO LOW = Active; GPIO HIGH = Inactive |
| IN17 | PB6 | GPIO LOW = Active; GPIO HIGH = Inactive |
| IN18 | PB7 | GPIO LOW = Active; GPIO HIGH = Inactive |

Safe-startup contract:

```text
MCU reset / GPIO high-Z
  -> MCU-side 10 kohm pulls Source to 3V3
  -> Gate = Source ~= 3.3 V, so VGS ~= 0 V
  -> 2N7002 OFF
  -> 24 V-side 10 kohm keeps the CM35 input HIGH / inactive
```

This hardware default does not depend on firmware initialization timing.

### CM35 → STM32 status

| CM35 output | STM32 GPIO | Physical behavior |
| --- | --- | --- |
| OUT1 | PA2 | CM35 Active → MCU LOW; Inactive → MCU HIGH |
| OUT2 | PA3 | CM35 Active → MCU LOW; Inactive → MCU HIGH |
| OUT3 | PA4 | CM35 Active → MCU LOW; Inactive → MCU HIGH |
| OUT4 | PA5 | CM35 Active → MCU LOW; Inactive → MCU HIGH |
| OUT5 | PA6 | CM35 Active → MCU LOW; Inactive → MCU HIGH |
| OUT6 | PA7 | CM35 Active → MCU LOW; Inactive → MCU HIGH |
| OUT7 | PB10 | CM35 Active → MCU LOW; Inactive → MCU HIGH |
| OUT8 | PB11 | CM35 Active → MCU LOW; Inactive → MCU HIGH |

Firmware remains responsible for translating the physical Active-Low GPIO state to the positive application/protocol semantic.

## Field Connectors

- CM35 IN connector `CN6`: Cixi Kefa Elec `KF2EDGR-3.81-8P` PCB header, LCSC/JLCPCB `C441188`, pins ordered IN11 through IN18.
- CM35 OUT connector `CN5`: the same `KF2EDGR-3.81-8P` PCB header, pins ordered OUT1 through OUT8.
- Stage 5 placement evidence confirms the physical board relationship used for routing review: `CN6` is the left-side IN11–IN18 interface and `CN5` is the right-side OUT1–OUT8 interface. This current mapping supersedes the earlier reversed documentation wording.
- Matching removable plug baseline: Cixi Kefa Elec `KF2EDGK-3.81-8P`, LCSC `C440864`, 8-position / 3.81 mm plug. Final mate fit、board-edge access、wiring clearance and enclosure acceptance remain mechanical verification items.
- Current CM35 connector reference designators are `CN5` / `CN6`; other exact reference designators remain governed by the current `.SchDoc` / `.PcbDoc` implementation.

## Evidence and Remaining Validation

- The GPIO tables above are synchronized to the locked Stage 6 routing-driven baseline in `README.md` and `docs/pcb_review.md`; they supersede this module's earlier placement-era mapping.
- Current-session Altium screenshots support the visible 16-channel topology, rail naming, mapping, and Stage 5 placement relationship described above.
- The user confirmed correction of prior `24V` labels to `24V_PROTECTED` and all low-voltage rail labels to `3V3`.
- The `.SchDoc` remains the schematic implementation authority and the `.PcbDoc` remains the PCB implementation authority. Basic industrial control behavior has been exercised, but the complete CN6 control table, CN5 status table, reset/initialization/power-down safety states, connector mate fit, EMC, and surge behavior remain to be recorded.

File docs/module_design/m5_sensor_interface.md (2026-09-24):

# M5 — Photoelectric Sensor Interface

## Module Status and Boundary

- Responsibility: power 4 × AN-LS18-40-N sensors and acquire each sensor's NPN NO and NC outputs, for 8 MCU inputs total.
- Per-channel frontend baseline: **CAPTURED / REVIEWED ACROSS ALL 8 CHANNELS**.
- EDA capture status: **CLOSEOUT ACCEPTABLE**. Sensor 1–4 NO / NC have all been captured and passed the current-session screenshot-level completeness review.
- Stage 4 Formal Schematic Review is **PASS / CLOSED** and PCB Layout entry is approved. This conclusion does not claim `.SchDoc` object parsing, broader full-board footprint verification, ERC PASS, EMC/surge compliance, or hardware-test PASS.

## Sensor Connectors and GPIO Mapping

Sensors 1–4 use connectors `CN1`–`CN4`, respectively. Each is one Cixi Kefa Elec `KF2EDGR-3.81-4P` PCB header, LCSC/JLCPCB `C441184`, with identical field wiring:

| Pin | PCB net / function | Sensor wire |
| --- | --- | --- |
| 1 | `24V_PROTECTED` | Brown |
| 2 | `GND` | Blue |
| 3 | NO field signal | Black |
| 4 | NC field signal | White |

The matching removable 3.81 mm plug is required; its exact MPN remains a procurement/mechanical confirmation item. Current sensor connector reference designators are `CN1`–`CN4`.

| Sensor signal | STM32 GPIO |
| --- | --- |
| SENSOR1_NO | PB8 |
| SENSOR1_NC | PB9 |
| SENSOR2_NO | PA0 |
| SENSOR2_NC | PA1 |
| SENSOR3_NO | PB12 |
| SENSOR3_NC | PB13 |
| SENSOR4_NO | PB14 |
| SENSOR4_NC | PB15 |

## Per-channel Frontend Baseline

Each NO or NC field signal retains the current 2N7002 device, LCSC `C7420321`; Nexperia `2N7002,215` remains qualification history/reference rather than a mandatory/current Primary replacement. Each channel uses the following topology:

```text
FIELD signal -> 100 ohm -> 24 V-side node -> 2N7002 Drain
                           |
24V_PROTECTED -> 10 kohm --+

2N7002 Gate -> 3V3
2N7002 Source -> MCU-side signal -> STM32 GPIO
                                  |
                       3V3 -> 10 kohm

FIELD signal -> SMF30A cathode
GND          -> SMF30A anode
```

The TVS belongs on the connector side of the 100 Ω resistor and physically close to the field connector, with a short return to `GND`. NPN output asserted / sinking produces MCU GPIO LOW; output released produces MCU GPIO HIGH. Firmware converts this Active-Low physical state to positive application semantics.

NO and NC are acquired together to support complementary-state diagnostics. Firmware may use disagreement from the expected complementary relationship to detect wiring, sensor, or stuck-signal anomalies, but must allow for brief non-complementary states during switching and must not declare a fault immediately from a transient mismatch. No diagnostic coverage or functional-safety claim is made at this stage.

## Protection and Filtering Decision

- Series resistor: `100 Ω`, fitted baseline.
- TVS: Littelfuse `SMF30A`, unidirectional, SOD-123FL, LCSC `C720060`, fitted on every NO and NC field signal.
- Littelfuse official data: `VRWM = 30 V`; `VBR = 33.3–36.8 V @ 1 mA`; maximum `VC = 48.4 V @ 4.1 A` for a 10/1000 µs pulse; 200 W peak-pulse class.
- Suitability basis: 30 V stand-off is above the nominal 24 V signal, while the specified 48.4 V clamp point is below the 2N7002's 60 V `VDS` rating. This provides a useful schematic-level transient-protection margin for ESD, insertion, and occasional field-cable transients.
- Limitation: that comparison does not prove a system surge or EMC level. Actual source impedance, pulse shape, cable/trace inductance, TVS tolerance, placement, and MOSFET terminal overshoot remain later verification items.
- RC/filter capacitor: **NOT FITTED**, with no DNP capacitor footprint required in Rev.A. Current installation evidence does not show sustained noise that justifies hardware RC filtering; later waveform evidence may instead lead to software filtering or a measured hardware change.
- M5, the sensors, the PCB, and CM35 I/O all belong to the isolated PSU-B I/O domain. PSU B directly powers CM35 `V/G` and feeds the PCB `24V/GND` input; the sensors receive `24V_PROTECTED/GND` through the PCB branch. No per-channel galvanic isolation or PCB isolated DC/DC is added.

The SMF30A is an ordinary Stage-3 support/protection component decision. Its verified selection does not reopen Stage 2 because it does not change the architecture, safety boundary, or interface voltage class.

## Closeout and Evidence Boundary

- The GPIO table above is synchronized to the locked Stage 6 routing-driven baseline in `README.md` and `docs/pcb_review.md` and supersedes the earlier placement-era Sensor 2 allocation.
- Current-session screenshots show all four `KF2EDGR-3.81-4P` sensor connectors and all eight NO/NC frontends, including 8 × 100 Ω series resistors, 8 × field-side SMF30A TVS devices, 8 × 2N7002, 24 V-side 10 kΩ pull-ups, `3V3` gates, MCU-side 10 kΩ pull-ups, and the SENSOR1–SENSOR4 NO/NC GPIO mapping.
- The TVS remains on the connector side of each 100 Ω resistor. The repeated implementation preserves `3V3`, `24V_PROTECTED`, TVS polarity, resistor placement, and GPIO mapping.
- Screenshot review does not equal `.SchDoc` object parsing. Complete object/net connectivity, exact reference designators, footprints, ERC, EMC/surge performance, and measured hardware behavior remain outside this closeout evidence.
- No actual four-sensor, NO/NC, or eight-channel result was provided for this documentation update. No sensor channel is marked PASS; the recommended per-channel procedure is in [`docs/bringup_log.md`](../bringup_log.md).

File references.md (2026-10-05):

# Reference Index

关键参数必须回到 official manufacturer datasheet、reference manual 或 application note 核对。商品页只用于采购与装配信息，不能替代官方技术证据；Legacy Project 资料只作为本 Project 的参考和既有功能证据。

## Project Inputs and Legacy Evidence

| Item | Source | Role | Current State | Local Path or Link |
| --- | --- | --- | --- | --- |
| Project initialization brief | 用户在 2026-08-29 提供的任务说明 | Requirements / interface contract fact input | Reviewed | Conversation record; no local file |
| Previous-generation schematic PDF | 用户提供的上一代原理图 | Legacy Design Reference / Existing Functional Evidence；不是本项目 EDA authority | Stage 2 technical comparison performed；确认主要 24 V ↔ 3.3 V conversion 使用 2N7002 MOSFET networks；legacy power 使用 XL7005A | [references/旧原理图.pdf](references/旧原理图.pdf) |
| Previous-generation BOM spreadsheet | 用户提供的上一代 BOM | Legacy Design Reference；旧器件仍需重新 qualification | Archived; full BOM comparison not performed | [references/旧BOM表.xlsx](references/旧BOM表.xlsx) |
| AN-LS18-40-N photoelectric sensor manual | User-provided external-device manual | External Device Reference | Reviewed during design; manufacturer provenance remains unconfirmed | Original third-party PDF is not redistributed in the public repository |
| Existing 24 V PSU photo + user measurement | 用户在 2026-08-29 会话提供的产品图片和万用表测量 | Current power-source operating-point evidence | Product image shows `MS-120-24`, nominal 24 V / 5 A / 120 W；user measured output ≈24 V and observed stable | Conversation record; no repository file |
| CM35 official I/O pages | 用户在当前工程会话提供的官方手册页面 | User-provided Official-Manual Evidence | Reviewed：`V/G` 明确定义为 isolated I/O 24 V positive/24G negative，`24V/0V` 为 controller system supply；手册建议 system 与 I/O 使用 isolated / non-common-ground switching supplies，示例使用两套 24 V switching supplies | Conversation/session evidence；当前本地 manual PDF 未跟踪，不声称已由本 commit 归档 |
| M3 Altium schematic screenshot | 用户在当前 Stage-3 会话提供的 M3 schematic screenshot | Current-session EDA Evidence | Reviewed for USB-C / USBLC6 / CH340C / ISO7721 connections and domain separation；supports module `CLOSEOUT ACCEPTABLE` only | Conversation record；`.SchDoc` is not parsed or modified by this documentation sync |
| M1 reverse-polarity schematic evidence + user Altium mapping confirmation | 用户在 Stage 4 提供的 schematic evidence 与最终 Altium 核对结果 | Current-session EDA Evidence | Supports the corrected `24V_IN_RAW` / `GND_IN_RAW`, Q25/R65/R66/D12 topology；user confirmed Q25 symbol D/G/S ↔ PowerDI3333-8 pads ↔ manufacturer pinout；SR-M1-001 CLOSED | Conversation record；does not prove `.SchDoc` parser coverage, ERC, broader full-board footprint mapping, hardware behavior, or EMC/surge compliance |
| M4 Altium schematic screenshots | 用户在当前 Stage-3 会话提供的 M4 schematic screenshots | Current-session EDA Evidence | Visible 16-channel 2N7002 topology、`3V3` / `24V_PROTECTED` rails、mapping and safe-startup reviewed；supports M4 `CLOSEOUT ACCEPTABLE` only | Conversation record；does not prove `.SchDoc` objects、ERC、footprints、Stage 4 or PCB Layout |
| M5 complete 8-channel schematic screenshots | 用户在 Stage 3 提供的完整 M5 screenshots | Current-session EDA Evidence | Sensor 1–4 NO/NC 共 8 路 visible completeness reviewed：CN1–CN4、8 × 100 Ω、8 × SMF30A、8 × 2N7002、24 V-side / MCU-side pull-ups、`3V3` gates and GPIO mapping；supports M5 `CLOSEOUT ACCEPTABLE` | Conversation record；screenshot review does not prove `.SchDoc` objects、footprints、ERC、EMC/surge or hardware behavior |
| Stage 4 complete schematic PDF | 2026-09-01 current full-board export | Stage 4 formal-review evidence | Archived and used as the current complete schematic evidence for Stage 4 PASS / CLOSED | [hardware/outputs/SCH_Schematic1_2026-09-01.pdf](hardware/outputs/SCH_Schematic1_2026-09-01.pdf) |
| Stage 4 current BOM | 2026-09-01 current BOM export | Stage 4 formal-review evidence | Archived and used as the current BOM evidence for Stage 4 PASS / CLOSED | [hardware/outputs/BOM_Board1_Schematic1_2026-09-01.xlsx](hardware/outputs/BOM_Board1_Schematic1_2026-09-01.xlsx) |

Legacy schematic 与 BOM 不自动成为本项目 EDA authority。用户已明确授权复用上一代 MOSFET level-conversion idea；Stage 2 仍以当前器件 official data 重新 qualification，Stage 3 新 `.SchDoc` 才是 implementation authority。

## Official Technical Sources

| Item / Module | Official source | Key facts used | Review Status |
| --- | --- | --- | --- |
| STM32F103C8T6 | STMicroelectronics STM32F103C8 product / datasheet / reference manual | 2.0–3.6 V device family、72 MHz、LQFP-48 option、minimum-system and GPIO/USART/SWD resources | Stage 2 core selection reviewed；M2 Stage-3 implementation decisions recorded, current-session closeout acceptable |
| LMR36510FADDAR | [Texas Instruments LMR36510 product / datasheet](https://www.ti.com/product/LMR36510) | 4.2–65 V input、1 A synchronous buck、400 kHz FPWM orderable option、application and external-component guidance | Reviewed for Primary selection；M1 Stage-3 external implementation recorded, remaining validation bounded |
| SWPA6045S220MT | [Sunlord SWPA Series official datasheet](https://www.sunlordinc.com/uploads/files/20221122/SWPA%20series%20of%20SMD%20Power%20Inductor.pdf) | 22 µH ±20%；DCR 116 mΩ max / 89 mΩ typ；Isat 2.05 A min / 2.20 A typ；Irms 1.80 A max / 2.00 A typ；SWPA6045 = 6 × 6 × 4.5 mm shielded construction | Manufacturer technical source reviewed for M1 L1 decision；end-application thermal/current verification remains |
| LMR36520FADDAR | [Texas Instruments LMR36520 product / datasheet](https://www.ti.com/product/LMR36520) | 4.2–65 V、2 A、400 kHz FPWM、DDA-8；TI states pin compatibility with LMR36510 | Qualified electrical scaling Alternate；purchase-time sourcing recheck required |
| STPS2H100A | STMicroelectronics STPS2H100 product / datasheet | 100 V / 2 A Schottky rectifier、SMA package | Reviewed for series reverse-polarity Primary |
| SMBJ30A-TR | STMicroelectronics SMBJxxA/CA datasheet | 30 V stand-off；600 W class 10/1000 µs TVS；clamp behavior depends on surge waveform/current | Reviewed for Primary selection; system surge margin calculation pending |
| 2N7002,215 | [Nexperia 2N7002 product / datasheet](https://www.nexperia.com/product/2N7002) | 60 V / 300 mA N-MOSFET、logic-level drive、logic-level translator application | Retained as useful qualification history/reference envelope；not a mandatory replacement for the accepted current C7420321 device |
| USB Type-C receptacle / CC termination | [USB-IF USB Type-C® Cable and Connector Specification — Document Library](https://www.usb.org/documents?search=usb+type+c) | Official Type-C receptacle / role / CC termination authority；USB 2.0 device/sink baseline uses independent Rd on CC1 and CC2 | Stage 3 M3 `5.1 kΩ` Rd on each CC line reviewed；USB-IF Release 2.5 is current at this review and should be rechecked if Type-C role or power behavior changes |
| ISO7721DR | [Texas Instruments ISO7721 product / datasheet](https://www.ti.com/product/ISO7721) | dual-channel digital isolator、1 forward + 1 reverse、2.25–5.5 V supplies、non-F default-HIGH behavior、independent side supplies | Stage 3 exact M3 side assignment、UART direction、decoupling and intended power-off behavior reviewed；current-session closeout acceptable |
| ISO6721BDR | [Texas Instruments ISO6721 product / datasheet](https://www.ti.com/product/ISO6721) | dual-channel 1 forward + 1 reverse、default HIGH、2.25–5.5 V plus 1.8 V support、SOIC-8；basic-isolation class | Qualified cost-focused Alternate only while Project has no reinforced-isolation requirement；substitution must preserve M3 power-state behavior |
| CH340C | [WCH CH340 official datasheet/download page](https://www.wch-ic.com/downloads/CH340DS1_PDF.html) | USB-to-UART、5 V supply option、V3 decoupling behavior、internal clock variant、SOP-16、USB/UART pins | Stage 3 M3 VCC/V3、D+/D-、TXD/RXD and unused-pin implementation reviewed；current-session closeout acceptable |
| USBLC6-2SC6 | [STMicroelectronics USBLC6-2 official datasheet](https://www.st.com/resource/en/datasheet/usblc6-2.pdf) | 2-line USB 2.0 high-speed ESD protection、I/O1/I/O2 feed-through pin topology、VBUS/GND connection、low line capacitance | Stage 3 M3 exact line/VBUS/GND connection reviewed；current-session closeout acceptable |
| AN-LS18-40-N | User-provided manual; manufacturer provenance not yet confirmed | DC 10–30 V、NPN NO+NC、≤10 mA static current、NO/NC wiring、200 mA max output-load statement | Technical content available; manufacturer authority not confirmed |
| CM35 controller | User-provided official-manual pages | Input pull-to-24G active；anti-interference filtering with ≥about 2 ms signal duration；OUT load between +24 V and output confirms sinking behavior；`V/G` = isolated I/O supply；`24V/0V` = system supply；isolated non-common-ground supplies are recommended and the example uses two 24 V switching supplies | Power-domain interpretation reviewed for Stage 3；exact internal isolation construction/rating and threshold/current/VOL/leakage are not inferred without explicit manual data |
| Littelfuse SMF30A | [Littelfuse SMF Series official datasheet](https://www.littelfuse.com/assetdocs/tvs-diodes-smf-datasheet?assetguid=7eb8a5b6-bdd0-4561-8f19-0c3cc6f9b2af) | Unidirectional `SMF30A`；SOD-123FL；`VRWM=30 V`；`VBR=33.3–36.8 V @ 1 mA`；maximum `VC=48.4 V @ 4.1 A` for 10/1000 µs；200 W class | Reviewed for M5 Stage-3 field-signal TVS baseline；system surge/EMC performance remains unverified |
| F1 one-time fuse | [Littelfuse 468 Series datasheet](https://www.littelfuse.com/assetdocs/fuse-468-datasheet?assetguid=6b7857dc-f79c-4aae-8bcc-a9ef11ddef09) | 0468.500NRHF：0.5 A、63 V、1206 Slo-Blo、50 A interrupt at 63 VAC/VDC；25% continuous derating plus temperature re-rating | Reviewed for Primary；final startup/local-temperature check remains Stage 3 |
| F1 resettable Alternate | [Littelfuse 1210L Series PPTC datasheet](https://www.littelfuse.com/assetdocs/resettable-ptcs-1210l-datasheet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) | 1210L035/60PR：0.35 A hold / 0.70 A trip at 20°C、60 V、10 A；hold falls to 0.21 A at 70°C、R1max 1.5 Ω | Alternate architecture only；temperature/heating/residual-current limitations prevent Primary selection |

## Procurement Sources — LCSC / JLCPCB

Point-in-time supplier observations must be rechecked before purchasing / PCBA submission.

| Function | Manufacturer / MPN | LCSC C# | Procurement State on 2026-08-29 | Technical Limitation |
| --- | --- | --- | --- | --- |
| MCU | ST STM32F103C8T6 | C8734 | Listing confirmed | Supplier page does not replace ST datasheet |
| USB-UART | WCH CH340C | C84681 | Good / listed with substantial stock during check | Supplier data does not replace WCH datasheet |
| UART isolation | TI ISO7721DR | C366164 | Listing confirmed | Supplier data does not replace TI datasheet |
| USB ESD | ST USBLC6-2SC6 | C7519 | Listing confirmed | Supplier data does not replace ST datasheet |
| USB-C receptacle | Korean Hroparts Elec TYPE-C-31-M-12 | C165948 | Listing confirmed | Mechanical acceptance still depends on enclosure / board-edge constraints |
| MOSFET conversion | 2N7002 current supplier listing | C7420321 | Intentionally retained from the previous working board for the current low-current level-translation application | Nexperia `2N7002,215` remains reference history, not a mandatory/current Primary replacement requirement；normal purchase-time identity and footprint checks still apply |
| Buck output capacitors C14/C15/C16 | Samsung CL31B226KPHNNNE, 22 uF / 10 V / X7R / 1206 | C87996 | Current selected output-capacitor record | Supplier identity does not replace DC-bias/effective-capacitance validation |
| 24 V → 3.3 V | TI LMR36510FADDAR | C1858394 | Good / in stock during check | Supplier data does not replace TI design procedure |
| Reverse-polarity diode | ST STPS2H100A | C81548 | Listing confirmed | Final dissipation depends on board current budget |
| 24 V TVS | ST SMBJ30A-TR | C133663 | Good / in stock during check | Surge compliance cannot be inferred from supplier listing |
| Input fuse | Littelfuse 0468.500NRHF | C206993 | Listing re-confirmed during 2026-08-30 closeout | Supplier listing confirms MPN/package only；technical qualification uses Littelfuse datasheet |
| PPTC Alternate | Littelfuse 1210L035/60PR | C28661880 | Listing found during 2026-08-30 closeout；availability not frozen | Temperature-dependent hold behavior limits application |
| Buck output inductor | Sunlord SWPA6045S220MT | C83454 | Listing confirmed for the user-frozen L1 selection | Procurement/package evidence only；electrical qualification uses Sunlord official SWPA datasheet |
| CM35 8P PCB header | Cixi Kefa Elec KF2EDGR-3.81-8P | C441188 | Listing confirmed on 2026-08-31 | Matching removable plug exact MPN and final mate/mechanical acceptance remain to be confirmed |
| Sensor 4P PCB header | Cixi Kefa Elec KF2EDGR-3.81-4P | C441184 | Listing confirmed on 2026-08-31 | Matching removable plug exact MPN and final mate/mechanical acceptance remain to be confirmed |
| Sensor field-signal TVS | Littelfuse SMF30A | C720060 | Exact Littelfuse listing and SOD-123FL package confirmed on 2026-08-31 | Supplier evidence does not replace Littelfuse official electrical data |

## Evidence Interpretation Notes

- User measurement of the existing PSU at approximately 24 V is Measured Evidence for the present operating point only. It does not prove regulation tolerance、ripple、surge waveform、OVP threshold or long-term stability.
- The product image for `MS-120-24` is not treated as a manufacturer official datasheet; its 24 V / 5 A / 120 W marking is used only as user-provided equipment identification evidence.
- The external PSU 5 A capability must not be used as the PCB input fuse/current-limit value. Board protection is sized from the board load budget and fault-energy boundary.
- The earlier requirements wording that described legacy CM35 readback as optocoupler-based conflicted with the archived schematic. Stage 2 inspection supports a 2N7002 MOSFET conversion baseline, and `requirements.md` has been corrected accordingly.
- The user-provided CM35 official-manual evidence is sufficient for Stage-2 topology qualification but not for exact electrical parameter claims. A local CM35 PDF present during this work remains untracked and is not represented as repository-archived evidence.
- The current-session M3 screenshot is EDA evidence for the visible connections only. It does not prove the underlying `.SchDoc` object model, footprints, ERC, PCB isolation geometry, enumeration, powered/unpowered behavior, or measured isolation performance.
- The current-session M4 and complete M5 screenshots support only the visible module implementation and module closeout boundaries. They do not prove `.SchDoc` objects、ERC、footprints、Stage 4、PCB Layout、EMC/surge compliance or hardware behavior.
- The current-session M1 schematic evidence supports the visible Q25 low-side reverse-polarity topology. The user separately completed the final Q25 D/G/S ↔ PowerDI3333-8 pads ↔ manufacturer-pinout check in Altium; this closes SR-M1-001 without claiming broader full-board footprint verification.
- The 2026-09-01 schematic PDF and BOM are tracked under `hardware/outputs/` as the current Stage 4 formal-review evidence. Their archive and the Stage 4 decision do not constitute ERC, hardware-test, `.SchDoc` parser, or EMC/surge compliance evidence.

## Missing Evidence / Remaining Qualification

| Topic | Required Source | Decision Blocked | Priority | Evidence State |
| --- | --- | --- | --- | --- |
| STM32 minimum-system details | ST datasheet/reference manual/application notes | Later layout implementation and hardware validation | High before applicable later gates | M2 decisions recorded；Stage 4 closed；no `.SchDoc` parsing, ERC, or hardware-test claim |
| CM35 exact I/O electrical parameters | CM35 official manual/datasheet pages containing threshold/current/VOL/leakage | Later formal verification against exact external-device limits | High; needed by formal review | Rev.A two-PSU power domain and M4 module design closed；exact CM35 electrical parameters and internal isolation rating remain unavailable |
| AN-LS18-40-N manufacturer provenance | Manufacturer official datasheet or confirmed provenance of archived manual | Later formal verification against exact sensor output limits | High; needed by formal review | M5 per-channel baseline defined from available evidence；manufacturer authority remains open |
| External PSU official tolerance/surge data | Manufacturer official datasheet if obtainable | Required only for tighter PSU-specific or compliance-level surge claims | Medium | User nominal image + ≈24 V measurement available; official spec absent |
| Mechanical envelope | Enclosure, board size, mounting and wiring constraints | Final USB/terminal mechanical selection and PCB outline | High; freeze before Stage 5 | Open；TYPE-C-31-M-12 remains mechanical-conditional |
| M3 implementation validation | Current schematic PDF/BOM/EDA evidence plus later hardware test | ERC/footprint completeness、USB enumeration、UART communication、independent power sequencing、PCB isolation geometry、EMC/ESD | High before applicable later gates | M3 current-session screenshot reviewed；module design closeout acceptable, validation remains open |
| Detailed board power validation | Output-capacitor DC-bias data、startup/inrush evidence、thermal and layout evidence | F1 startup coordination、effective capacitance、thermal and switch-current-loop verification | High; needed before the applicable later gates | C14/C15/C16 frozen as C87996；SR-M1-001 and Q25 mapping are closed；remaining items do not reopen Stage 4 |

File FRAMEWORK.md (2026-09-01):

# Framework Binding

Framework Repository: wum747349-debug/Hardware-Project-Framework
Framework Release: development-v1.2.0
Framework Commit: 4597775c2bc21aef28cf58525e2192a7de69a454
Project Structure Version: 1
Repository Model: Standalone Project
Initialization Framework Release: hardware-project-framework-v1.1.1
Initialization Status: Initialized

Bootstrap 必须替换全部尖括号 placeholder。正式 Project 绑定固定已发布 Release 及其 immutable Commit，不跟随 Framework `main`。

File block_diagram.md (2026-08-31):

# Block Diagram

本文件描述模块、能量流、信号流和系统边界；它不证明器件已选择或 EDA 已实现。

## System Boundary

```text
                         PC / C# upper computer
                                  ↕ USB
                    ┌───────────────────────────────┐
                    │ M3 — USBLC6 + CH340C          │
                    │ USB_VBUS / USB_GND domain     │
                    └───────────────↕ UART──────────┘
                         ║ galvanic isolation ║
                         ║   boundary (UART)  ║
                    ┌───────────────↕───────────────┐
                    │ ISO7721 isolated UART         │
                    │ USB_GND ≠ machine GND         │
                    └───────────────↕───────────────┘
                                    │
PSU B isolated I/O supply          │
  +24 V / -V                ┌───────↕────────┐
        │                   │ M2 — STM32F103 │
        ▼                   │ minimum system │
┌───────────────────┐       └───↕────────↕───┘
│ M1 — F1 / STPS /  │           │        │
│ SMBJ30A / LMR36510│           │        │
│ Protection + 3V3 │           │        │
└──────┬────────────┘           │        │
       │ 24V_PROTECTED / 3V3    │        │
       ├────────────────────────┘        │
       │                                 │
       ▼                                 ▼
┌──────────────────────┐       ┌───────────────────────────┐
│ M5 — 4 × Sensor      │       │ M4 — CM35 Industrial I/O │
│ 4 × (NO + NC)        │       │ 8 × STM32 → IN11–IN18    │
│ = 8 sensor inputs    │       │ 8 × OUT1–OUT8 → STM32    │
└──────────↕───────────┘       └────────────↕──────────────┘
  4 × AN-LS18-40-N                  CM35 I/O V/G domain
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

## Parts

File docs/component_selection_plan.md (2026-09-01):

# Critical Component Selection Plan

本文件是 Stage 2 — Critical Component Selection 的 selection decision 主记录。关键器件先于普通外围器件确定；本文件不构成最终 BOM、EDA implementation 或 Stage completion 证明。

## Stage 2 Current State

- Selection activity：Closeout complete
- Critical component candidates：Recorded
- Primary decisions：Recorded for current first-pass scope
- Deferred peripherals：Routed to Stage 3 / Stage 5 owners；not Stage-2 blockers
- EDA implementation：Not started
- Stage 2 complete：YES
- Closeout decision：PASS

## Confirmed Inputs

- 主控：STM32F103C8T6 直接集成到 PCB。
- 通信：board-mounted USB-UART，经 galvanically isolated UART interface 连接 machine-side STM32；PC USB ground 与 machine-side 24 V `0V` 不直接共地。
- CM35：使用 IN11–IN18 与 OUT1–OUT8，共 8 路 control + 8 路 status；physical interface 为 Active-Low contract。
- Sensor acquisition：4 个 AN-LS18-40-N 的 NO + NC 均采集，共 8 路 digital inputs。
- 制造目标：JLCPCB / LCSC 与 SMT / PCBA preferred。
- 24 V source：用户提供的电源图片显示 `MS-120-24`、24 V / 5 A / 120 W；用户已用万用表确认当前实际输出约 24 V 且观察较稳定。该测量只证明当前 operating point，不证明电源 tolerance、surge 或 protection performance。
- Legacy conversion：用户明确授权复用上一代 I/O 转换思路；已检查归档旧原理图，主要转换器件为 2N7002 MOSFET，而不是 optocoupler。新设计仍需在 Stage 3 对 exact connection、resistor values、safe state 与 external-interface protection 重新核对。
- CM35 official I/O evidence：用户提供的官方资料页面确认 input pull-to-24G active、输入过滤要求信号保持至少约 2 ms、OUT1–OUT8 采用 low-side/sinking external connection、`V/G` 为 I/O 隔离 24 V power domain；不据此声称 exact threshold/current 或内部 transistor topology。
- Channel scope：用户已明确确认实际使用设备存在 IN15–IN18，Project 继续保留 IN11–IN18 + OUT1–OUT8。

## Primary Candidate Table

Availability 为 2026-08-29 的 point-in-time procurement evidence；未取得明确库存数量时不推断库存状态。

| Module | Function | JLC C# | Manufacturer | MPN | Package | Availability | Key requirements / qualification basis | Datasheet verified | Decision | Notes |
| --- | --- | --- | --- | --- | --- | --- | --- | --- | --- | --- |
| M2 | MCU | C8734 | STMicroelectronics | STM32F103C8T6 | LQFP-48 | Unknown | 2.0–3.6 V、72 MHz、37 I/O class、USART/SWD resources；Project requirement 指定 | Yes | Primary | Exact GPIO / clock / boot / reset / VDDA implementation 留待 Stage 3 |
| M3 | USB-UART | C84681 | WCH | CH340C | SOP-16 | Good | USB 2.0 Full-Speed to UART、3.3/5 V supply、built-in clock、2 Mbps class | Yes | Primary | -20~+70 °C；若后续环境温度要求超出范围需重新评估 |
| M3 | UART galvanic isolation | C366164 | Texas Instruments | ISO7721DR | SOIC-8 | Unknown | 2 channels, 1 forward + 1 reverse；2.25–5.5 V each side；default output HIGH；适合 UART TX/RX domain isolation | Yes | Primary | USB side 与 machine side 分别由各自电源域供电；不因此声称 system-level isolation certification |
| M3 | USB data ESD | C7519 | STMicroelectronics | USBLC6-2SC6 | SOT-23-6L | Unknown | 2-line USB 2.0 high-speed ESD protection；low line capacitance | Yes | Primary | Placement / routing / VBUS connection 留待 Stage 3/5 |
| M3 | USB-C receptacle | C165948 | Korean Hroparts Elec | TYPE-C-31-M-12 | SMD, right-angle, 16P | Unknown | USB 2.0 device connection；JLC/LCSC sourcing convenient | Supplier data | Conditional | Electrical use acceptable for current concept；mechanical/enclosure qualification remains OPEN-003 |
| M4/M5 | 24 V ↔ 3.3 V open-drain / pull-down conversion | C7420321 | Current supplier listing | 2N7002 | SOT-23 | Retained | Same C-number used on the previous working board；accepted for the current low-current level-translation application | Legacy/application evidence；Nexperia reference retained | Primary / retained | Do not require replacement with Nexperia `2N7002,215` solely because earlier documentation named it Primary；normal purchase-time identity and footprint checks still apply |
| M1 | 24 V → 3.3 V buck | C1858394 | Texas Instruments | LMR36510FADDAR | HSOIC/ESOP-8 | Good | 4.2–65 V input、1 A synchronous buck、400 kHz FPWM、70 V transient tolerance class、industrial-oriented protection features | Yes | Primary | Inductor、FB、input/output capacitors、thermal/load budget deferred to Stage 3 |
| M1 | Reverse-polarity protection | C81548 | STMicroelectronics | STPS2H100A | SMA (DO-214AC) | Unknown | 100 V / 2 A Schottky series diode；simple fail-safe reverse-polarity blocking for low-current 24 V control board | Yes | Primary | Forward drop / dissipation to be checked against final current budget |
| M1 | 24 V transient suppression | C133663 | STMicroelectronics | SMBJ30A-TR | SMB (DO-214AA) | Good | 30 V stand-off；600 W class 10/1000 µs TVS；selected above measured ~24 V steady source and below LMR36510 high-voltage boundary | Yes | Primary | ST table gives higher clamp under 8/20 µs high-current condition; Stage 3 must check source impedance, surge assumption and margin before claiming a compliance level |
| M1 | Input overcurrent protection | C206993 | Littelfuse | 0468.500NRHF | 1206 | Unknown | 0.5 A / 63 V Slo-Blo；50 A interrupt at 63 VAC/VDC；manufacturer continuous and temperature derating applied to 0.225 A design envelope | Yes | Primary | Final Cin/startup pulse and local-temperature check remain Stage 3 |

## Stage-2 Bounding Power Budget

This budget selects current classes only. It is not a detailed startup、ripple、magnetics、thermal or compliance calculation.

| Load | Bounding allowance | Evidence / limitation |
| --- | ---: | --- |
| 4 × AN-LS18-40-N static sensor supply | ≤40 mA @ 24 V | User manual states ≤10 mA each；manufacturer provenance provisional |
| CM35 16-channel interface circuitry | 80 mA @ 24 V | Conservative 5 mA/channel allocation；exact CM35 current/impedance is not known |
| STM32F103C8T6 | 60 mA @ 3.3 V | Conservative selection allowance |
| ISO7721 machine-side supply | 10 mA @ 3.3 V | Logic-rate allowance |
| Machine-side pull-ups / interface logic | 40 mA @ 3.3 V | Bounding allowance pending exact values |
| Indicator / support allowance | 40 mA @ 3.3 V | Ordinary peripheral allowance |
| 3.3 V engineering reserve | 100 mA @ 3.3 V | Total 3.3 V design envelope = 250 mA |

Using 75% buck efficiency for a deliberately conservative Stage-2 conversion, the 250 mA / 3.3 V output envelope draws about 46 mA at 24 V. Sensors + CM35 allocation + buck input total about 166 mA; rounding to a **225 mA continuous 24 V design envelope** adds about 59 mA board-level reserve.

Conclusions:

- LMR36510FADDAR：0.25 A envelope vs 1 A class → **PASS**, about 4× current-class headroom.
- STPS2H100A：0.225 A envelope vs 2 A class → **PASS**, about 8.9× current-class headroom before exact forward-loss/thermal calculation.
- Input protection：0.5 A time-delay fuse class is appropriate; external PSU 5 A is not used as F1 rating.

## Primary Decisions

### M1 — 24 V Input / Protection / Low-voltage Power

Current architecture decision:

```text
24V input
  -> 0468.500NRHF 0.5 A / 63 V Slo-Blo fuse
  -> STPS2H100A series reverse-polarity protection
  -> protected 24V bus
       -> SMBJ30A-TR to 0V for transient suppression
       -> Sensor / CM35 interface supply needs
       -> LMR36510FADDAR -> 3.3V machine-side rail
```

The external 24 V source has been measured by the user at approximately 24 V and observed stable. This supports the 30 V TVS stand-off choice for the current design assumption, but it is not a substitute for an official PSU tolerance/surge specification.

F1 rationale:

- Littelfuse specifies the 0.5 A 468 device for 50 A interrupting at 63 VAC/VDC and gives time-delay opening behavior suitable for inrush tolerance.
- Littelfuse requires 25% standard continuous derating plus temperature re-rating. Its 70°C example yields `0.75 × 0.80 × 0.5 A = 0.30 A`, about 33% above the 0.225 A Stage-2 envelope.
- Stage 3 must compare final DC/DC input capacitance and sensor startup with the time-current curve and verify local ambient. If usable continuous rating falls to or below 0.225 A, or nuisance opening is predicted, reassess the 468 Series 1 A member and verify its exact orderable MPN rather than silently increasing F1.
- The 50 A interrupting rating does not by itself prove coordination with the PSU peak fault current or field wiring；those source/fault-path inputs remain unverified, and no system safety-standard claim is made.

### M3 — USB-UART / Isolation

Current primary architecture:

```text
PC USB-C
  -> USBLC6-2SC6
  -> CH340C
  -> ISO7721DR isolation barrier
  -> STM32 UART
```

USB-side power/ground and machine-side 3.3 V / 0 V remain separate across the digital-isolator barrier. Detailed power-state, unplugged-state and back-power analysis remains a Stage 3 task.

### M4 / M5 — CM35 and Sensor I/O Conversion

The archived previous-generation schematic was reviewed in Stage 2 and shows repeated 2N7002 MOSFET conversion networks. The earlier project wording that described the legacy CM35 readback as optocoupler-based was inconsistent with that schematic evidence and is corrected in `requirements.md`.

The new board intentionally retains LCSC `C7420321` for the reused 2N7002 MOSFET conversion approach. The same C-number was used on the previous working board, and the present low-current level-translation application remains accepted. The earlier Nexperia `2N7002,215` qualification is preserved as useful technical history and a reference envelope, but it is not the mandatory/current Primary and does not by itself require replacement of C7420321. This remains a topology/application acceptance, not a declaration that every old resistor value or protection detail is automatically valid for the new board.

CM35 topology qualification is **PASS** for Stage 2:

- Input：pull/sink signal to `24G` is active；official material describes anti-interference filtering and requires at least about 2 ms signal duration.
- Output：official external wiring places the load between `+24 V` and OUT, supporting low-side / sinking behavior. No more specific internal transistor topology is claimed.
- Power domains：`V/G` is the isolated I/O 24 V supply and `24V/0V` is controller system power；the official recommendation is isolated, non-common-ground sources. Exact Project connection is a Stage-3 design input.
- Exact ON/OFF threshold、input current/impedance、maximum sink current、ON-state voltage、leakage and resistor/RC/protection values remain unknown. They do not block the Stage-2 topology decision.

Sensor qualification is **CONDITIONAL** for Stage 2: the user-provided manual supports 10–30 V、NPN、NO+NC、wiring and ≤10 mA static current, so the 2N7002 direction and current class can close. Manufacturer provenance and exact frontend values remain a Stage-3 evidence gate.

## Primary / Alternate Decisions

| Architecture-sensitive function | Primary | Alternate | Qualification / reassessment rule |
| --- | --- | --- | --- |
| 24 V → 3.3 V | LMR36510FADDAR, 65 V / 1 A | LMR36520FADDAR, 65 V / 2 A | Qualified electrical scaling Alternate；TI identifies DDA-8 pin compatibility. Use only if Stage-3 load/thermal results require it and recheck sourcing. |
| UART isolator | ISO7721DR | ISO6721BDR | Qualified cost-focused Alternate for 1-forward/1-reverse UART and default-HIGH behavior. ISO6721BDR is basic-isolation class；do not substitute if later requirements demand the ISO7721 reinforced-isolation capability. |
| Input overcurrent | 0468.500NRHF one-time 0.5 A / 63 V Slo-Blo fuse | 1210L035/60PR 60 V PPTC architecture | Alternate is temperature-conditional：0.35 A hold at 20°C falls to 0.21 A at 70°C；resistance/heating、residual current and sustained-fault behavior prevent Primary status. |
| 24 V / 3.3 V interface MOSFET | LCSC C7420321 2N7002, intentionally retained | Nexperia 2N7002,215 qualification history / reference envelope | Do not replace C7420321 solely because the earlier record named Nexperia Primary. Any actual purchase-time substitution must preserve the required voltage/current class, 3.3 V low-current application suitability, SOT-23 pin/footprint mapping, and temperature envelope. |

Purchase-time availability must be rechecked before ordering / PCBA submission；current stock observations are not permanent Project facts.

## Blocking / Deferred Boundary

Stage-2 closeout blockers：**None**.

Deferred to Stage 3:

- exact GPIO / USART allocation；MCU crystal/load capacitors、boot/reset values and ordinary decoupling；
- LMR36510 inductor、feedback divider、Cin/Cout、startup waveform、ripple、thermal and detailed loss calculations；
- exact CM35 / Sensor resistor、RC、ESD/transient/current-limiting networks and CM35 V/G reference/domain connection（closed in Stage 3 module records；Rev.A uses the isolated PSU-B I/O domain）；
- F1 final local-temperature/time-current verification and STPS2H100A exact forward-loss；
- LEDs、test points and ordinary peripherals。

Deferred to Stage 5 Layout Preflight:

- USB-C final mechanical acceptance；terminal exact series/MPN；
- PCB outline、mounting holes、enclosure and final wiring access。

Deferred to procurement:

- Primary/Alternate stock and price recheck immediately before purchasing / PCBA BOM submission。

Any new evidence that changes the 24 V architecture、fault-energy boundary、isolation requirement、interface voltage/current class or critical component qualification reopens Stage 2. Exact parameters listed above do not do so by themselves.

## Stage 2 Exit Review

- Critical architecture / safety / selection decisions：Closed for Stage 2.
- Bounding power budget：PASS.
- F1 Primary + Alternate architecture：Qualified with explicit Stage-3 verification rules.
- CM35 Stage-2 qualification：PASS.
- Sensor Stage-2 qualification：CONDITIONAL；not a closeout blocker.
- Primary / Alternate completeness：PASS with C7420321 intentionally retained and the Nexperia qualification preserved as reference history rather than a mandatory replacement rule.
- Stage 2 Closeout：**PASS**.

## Evidence Boundary

- Manufacturer official datasheet / product documentation is the technical qualification authority for critical devices.
- LCSC/JLC pages are procurement evidence for MPN, C-number, package and point-in-time availability; they do not replace manufacturer technical documentation.
- User multimeter observation is Measured Evidence for the present PSU operating point only; it does not establish long-term tolerance, ripple, surge or protection behavior.
- Legacy schematic is Legacy Design Reference / Existing Functional Evidence; topology reuse is explicitly authorized by the user, but the new Project `.SchDoc` will become EDA implementation authority only after Stage 3 capture.
- No ERC、DRC、EDA implementation、Manufacturing、Bring-up or Test PASS is claimed by this Stage 2 record.

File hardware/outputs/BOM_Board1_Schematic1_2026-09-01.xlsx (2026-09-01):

No. | Quantity | Comment | Designator | Footprint | Value | Manufacturer Part | Manufacturer | Supplier Part | Supplier
1 | 12 | 100nF | C1,C3,C5,C6,C8,C9,C17,C18,C19,C20,C21,C22 | C0603 | 100nF | 0603B104K500NT | FH(风华) | C30926 | LCSC
2 | 2 | 15pF | C2,C4 | C0603 | 15pF | CL10C150JB8NNNC | SAMSUNG(三星) | C1644 | LCSC
3 | 2 | 1uF | C7,C13 | C0603 | 1uF | CL10B105KA8NNNC | SAMSUNG(三星) | C29936 | LCSC
4 | 1 | 10uF | C10 | C0805 | 10uF | CL21A106KAYNNNE | SAMSUNG(三星) | C15850 | LCSC
5 | 1 | 2.2uF | C11 | C1206 | 2.2uF | CC1206KKX7R0BB225 | YAGEO(国巨) | C577211 | LCSC
6 | 1 | 220nF | C12 | C0805 | 220nF | CC0805KKX7R0BB224 | YAGEO(国巨) | C513710 | LCSC
7 | 3 | 22uF | C14,C15,C16 | C1206 | 22uF | CL31B226KPHNNNE | SAMSUNG(三星) | C87996 | LCSC
8 | 4 | KF2EDGR-3.81-4P | CN1,CN2,CN3,CN4 | CONN-TH_4P-P3.81_KF2EDGR-3.81-4P |  | KF2EDGR-3.81-4P | KEFA(科发) | C441184 | LCSC
9 | 2 | KF2EDGR-3.81-8P | CN5,CN6 | CONN-TH_8P-P3.81_KF2EDGR-3.81-8P |  | KF2EDGR-3.81-8P | KEFA(科发) | C441188 | LCSC
10 | 8 | SMF30A | D1,D2,D3,D4,D5,D6,D7,D8 | SOD-123FL_L2.7-W1.8-LS3.7-R-RD |  | SMF30A | Littelfuse(美国力特) | C720060 | LCSC
11 | 1 | STPS2H100A | D9 | SMA_L4.4-W2.6-LS5.0-RD |  | STPS2H100A | ST(意法半导体) | C81548 | LCSC
12 | 1 | SMBJ30A-TR | D10 | SMB_L4.6-W3.6-LS5.3-RD |  | SMBJ30A-TR | ST(意法半导体) | C133663 | LCSC
13 | 1 | USBLC6-2SC6 | D11 | SOT-23-6_L2.9-W1.6-P0.95-LS2.8-BL |  | USBLC6-2SC6 | ST(意法半导体) | C7519 | LCSC
14 | 1 | MMSZ5242B-7-F | D12 | SOD-123_L2.7-W1.6-LS3.7-RD-1 |  | MMSZ5242B-7-F | DIODES(美台) | C500776 | LCSC
15 | 1 | 0468.500NRHF | F1 | F1206 |  | 0468.500NRHF | Littelfuse(美国力特) | C206993 | LCSC
16 | 1 | LAIL-PZ2.54-2P-L | H1 | CONN-TH_LAIL-PZ2.54-2P-L |  | LAIL-PZ2.54-2P-L | 莱联 | C54950603 | LCSC
17 | 1 | LAIL-PZ2.0-5P-L | H2 | HDR-TH_LAIL-PZ2.0-5P-L |  | LAIL-PZ2.0-5P-L | LAILAN(莱联) | C54950582 | LCSC
18 | 1 | 22uH | L1 | IND-SMD_L6.0-W6.0_SWPA6045S | 22uH | SWPA6045S220MT | Sunlord(顺络) | C83454 | LCSC
19 | 1 | WJ500V-5.08-2P | P1 | CONN-TH_2P-P5.00_WJ500V-5.08-2P |  | WJ500V-5.08-2P | KANGNEX(康奈克斯电气) | C8465 | LCSC
20 | 24 | 2N7002 | Q1,Q2,Q3,Q4,Q5,Q6,Q7,Q8,Q9,Q10,Q11,Q12,Q13,Q14,Q15,Q16,Q17,Q18,Q19,Q20,Q21,Q22,Q23,Q24 | SOT-23-3_L2.9-W1.3-P1.90-LS2.4-BR |  | 2N7002 | R+O(宏嘉诚) | C7420321 | LCSC
21 | 1 | DMT10H015LFG-13 | Q25 | POWERDI3333-8_L3.3-W3.3-P0.65-LS3.7-BL-EP |  | DMT10H015LFG-13 | DIODES(美台) | C6021899 | LCSC
22 | 51 | 10kΩ | R1,R7,R8,R9,R10,R11,R12,R13,R14,R20,R21,R22,R23,R24,R25,R26,R27,R28,R29,R30,R31,R32,R33,R34,R35,R36,R38,R39,R40,R41,R43,R44,R45,R46,R47,R48,R49,R50,R51,R52,R54,R55,R56,R58,R59,R60,R61,R62,R63,R64,R65 | R0603 | 10kΩ | RC0603FR-0710KL | YAGEO(国巨) | C98220 | LCSC
23 | 8 | 100Ω | R2,R3,R4,R5,R15,R16,R17,R18 | R0603 | 100Ω | FRC0603F1000TS | FOJAN(富捷) | C2906981 | LCSC
24 | 2 | 0Ω | R6,R19 | R0603 | 0Ω | FRC0603F0000TS | FOJAN(富捷) | C2906974 | LCSC
25 | 2 | 100kΩ | R37,R66 | R0603 | 100kΩ | 0603WAF1003T5E | UNI-ROYAL(厚声) | C25803 | LCSC
26 | 1 | 43.2kΩ | R42 | R0603 | 43.2kΩ | FRC0603F4322TS | FOJAN(富捷) | C2930102 | LCSC
27 | 2 | 5.1kΩ | R53,R57 | R0603 | 5.1kΩ | FRC0603F5101TS | FOJAN(富捷) | C2907044 | LCSC
28 | 1 | TS-1088-AR02016 | SW1 | SW-SMD_L3.9-W3.0-P4.45 |  | TS-1088-AR02016 | XUNPU(讯普) | C720477 | LCSC
29 | 1 | STM32F103C8T6 | U1 | LQFP-48_L7.0-W7.0-P0.50-LS9.0-BL |  | STM32F103C8T6 | ST(意法半导体) | C8734 | LCSC
30 | 1 | LMR36510FADDAR | U2 | ESOP-8_L4.9-W3.9-P1.27-LS6.0-BL-EP-1 |  | LMR36510FADDAR | TI(德州仪器) | C1858394 | LCSC
31 | 1 | CH340C | U3 | SOP-16_L10.0-W3.9-P1.27-LS6.0-BL |  | CH340C | WCH(南京沁恒) | C84681 | LCSC
32 | 1 | ISO7721DR | U4 | SOIC-8_L5.0-W4.0-P1.27-LS6.0-BL |  | ISO7721DR | TI(德州仪器) | C366164 | LCSC
33 | 1 | TYPE-C-31-M-12 | USBC1 | USB-C_SMD-TYPE-C-31-M-12_1 |  | TYPE-C-31-M-12 | 韩国韩荣 | C165948 | LCSC
34 | 1 | 8MHz | X1 | CRYSTAL-SMD_4P-L3.2-W2.5-BL | 8MHz | SX32Y008000BC1T001 | TKD(泰晶) | C20617233 | LCSC

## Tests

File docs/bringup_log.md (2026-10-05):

# Hardware Bring-up Record and Recommended Test Plan

Project: STM32 24V Industrial I/O Bridge

Hardware Revision: Rev.C

Current Project Stage: see repository root `README.md`

## Document Boundary

This document deliberately separates two evidence classes:

- **Part A — Actual Bring-up Record** records only the hardware work confirmed by the user as already performed. It is not a reconstruction of a fully instrumented test session.
- **Part B — Recommended Bring-up & Hardware Test Plan** is a future test procedure. Its steps and expected behaviors are recommendations or design expectations, not completed tests or PASS evidence.

Creating this record does not mean that a new hardware test session occurred, does not create a formal system acceptance result, and does not execute a Project Stage transition.

# Part A — Actual Bring-up Record

## A1. Current Bring-up Status

- The physical PCB has completed actual hardware bring-up and practical debugging.
- Rev.C is the third hardware iteration and is currently in practical use.
- Basic 24 V power-on, board 3.3 V checking, STM32 programming, host communication, and industrial I/O functional debugging were performed.
- A complete quantified test report has not been provided. There is no basis here for declaring every channel, power-integrity parameter, abnormal supply condition, EMC/surge requirement, isolation withstand requirement, or full system acceptance criterion PASS.
- This documentation update records an already completed activity; it does not claim that another round of hardware testing was performed during the update.

## A2. Actual Debug Sequence

The following sequence is limited to the user's confirmed account. No unconfirmed inspection, current-limit setting, waveform capture, or per-channel step has been inserted.

1. A programmable DC power supply was set to 24 V.
2. The supply was connected to the PCB 24 V input terminal.
3. A multimeter was used at the board 3.3 V and GND test points to check the 3.3 V supply.
4. After confirming the 3.3 V output, an ST-Link was connected and STM32 firmware was programmed.
5. The host computer was connected for serial communication and basic industrial I/O functional debugging.
6. Control commands were sent from the host computer, and a multimeter was used to check the corresponding motion-controller input-terminal voltage.
7. The observed basic Active-Low behavior was approximately 24 V for the inactive state and approximately 0 V for the active state.

## A3. Known Results and Evidence Boundary

| Item | Confirmed actual result | Evidence limitation |
| --- | --- | --- |
| Machine-side power | The board was powered from a 24 V DC supply. | Exact input voltage at the terminals, current limit, steady-state current, inrush, load, and temperature were not recorded. |
| 3.3 V rail | The board 3.3 V rail was checked before connecting ST-Link. | No exact voltage, tolerance, ripple, startup waveform, or load-step record was provided. |
| STM32 | Firmware was programmed through ST-Link. | Firmware identity, programming log, reset/BOOT matrix, and long-duration runtime evidence were not provided. |
| Host communication | Host serial communication and basic functional debugging were performed. | Enumeration details, baud rate, error-rate/duration data, power-sequence matrix, and isolation performance were not provided. |
| Industrial control | Host commands were exercised and corresponding motion-controller input-terminal voltages were checked. | The tested channel subset and a complete channel-by-channel result table were not provided. |
| Active-Low behavior | Approximately 24 V was observed as inactive and approximately 0 V as active. | These are approximate behavioral observations, not precision limits or a complete electrical characterization. |
| CM35 status inputs and sensors | No additional actual result is recorded here. | No complete CN5 OUT1–OUT8 or four-sensor NO/NC channel record was provided; these items are not marked PASS. |

No test date, operator, serial number, exact measurement value, instrument model, current, ripple, waveform, abnormal-power result, EMC/surge result, isolation-withstand result, or complete system PASS is inferred where none was supplied.

# Part B — Recommended Bring-up & Hardware Test Plan

## How to Use This Plan

Execute the following steps on a clearly identified PCB/PCBA and firmware version. Record actual values as they are measured. Values described as **design expectation** must not be converted to PASS criteria until they have been checked against the applicable device documentation, CM35 documentation, sensor documentation, firmware behavior, and system requirements. Stop immediately for an unexplained short, reversed polarity, unexpected current, voltage collapse, smoke, odor, sound, or rapid temperature rise.

Recommended sequence:

```text
Pre-power inspection
-> current-limited power validation
-> STM32 minimum system
-> isolated USB-UART
-> CM35 control outputs
-> CM35 status inputs
-> photoelectric sensors
-> integrated system test
```

## B1. Debug Preparation and Pre-power Checks

### Purpose and setup

Use good lighting, magnification, a DMM, the current schematic/PCB documents, and connector pinout records. Disconnect the 24 V source, USB cable, ST-Link, CM35, sensors, and other field wiring before resistance or continuity checks. Discharge the board before interpreting resistance readings.

### Inspection and measurement order

1. Record the PCB/PCBA identity, visible revision/marking, assembly state, and intended firmware.
2. Inspect both sides for missing or wrong parts, solder bridges, insufficient solder, tombstoned parts, contamination, damaged traces, foreign metal, and connector damage.
3. Check orientation/polarity for U1/U2/U3/U4, Q25, D9/D10/D12, other diodes/TVS devices, polarized parts, USB-C, SWD, CN1–CN6, and the 24 V input connector against the authoritative EDA and assembly information.
4. Verify the 24 V input terminal polarity before attaching leads.
5. With all power removed, check for unexplained low resistance or hard continuity at:
   - `3V3` to PCB `GND`;
   - `24V_PROTECTED` to PCB `GND`;
   - `24V_IN_RAW` to `GND_IN_RAW` at the input terminal;
   - `USB_GND` to PCB `GND`, which must not have an unintended direct connection.
6. Reverse the DMM leads and allow readings to settle where appropriate. MOSFET body-diode paths, TVS devices, semiconductor junctions, and charging capacitors can produce polarity-dependent or time-varying readings; continuity beeps alone are not a sufficient short-circuit diagnosis.

The negative-input protection boundary is:

```text
GND_IN_RAW -> Q25 -> PCB GND
```

`GND_IN_RAW` and PCB `GND` are not an ordinary hard-wired common before Q25. Do not bypass Q25 with a jumper, instrument lead, supply return, or field wiring. When diagnosing this path, compare the measured behavior with the Q25 MOSFET topology and board power state rather than requiring simple zero-ohm continuity.

Record the inspected locations, DMM mode, lead polarity, settled reading/behavior, and disposition. If a suspected short cannot be explained from the circuit, do not apply power; isolate the affected rail by schematic section and inspect components before retesting.

## B2. Current-limited Power-up and Staged Power Validation

The implemented positive-rail path is:

```text
24V_IN_RAW -> F1 -> D9 -> 24V_PROTECTED -> LMR36510 -> 3V3
```

The return path crosses Q25 as described in B1.

### Initial supply setup

- Initially disconnect USB, ST-Link, CM35, sensors, and controllable external loads unless a specific test requires them.
- Set the bench supply to 24.0 V with output disabled, verify lead polarity at the loose connector, then connect it to the PCB 24 V input.
- Choose the initial current limit from the expected unloaded board consumption plus margin. If no prior current baseline exists, **0.10 A is only a conservative engineering starting point for an unloaded-board trial, not an acceptance limit**. Increase in small recorded steps only after checking that CC operation is caused by benign startup charging rather than a fault and that no abnormal heating occurs.
- The fitted 0.5 A fuse is an overcurrent protection component with its own time-current behavior; it is not the bench-supply current-limit setting and does not define normal board current.

### Power-up observations and nodes

1. Enable the supply while watching input current and the CV/CC indication. A brief charging transient and steady-state current are different observations; record both when the instrument supports it.
2. If the supply remains in CC, the voltage collapses, current rises unexpectedly, or a component heats rapidly, disable the output immediately. Recheck polarity and narrow the fault in the order input/protection, `24V_PROTECTED`, then `3V3`.
3. Measure the input terminal between `24V_IN_RAW` and `GND_IN_RAW`.
4. Measure `24V_PROTECTED` relative to PCB `GND` at a positively identified, mechanically safe access point.
5. Measure the top-side `3V3` test pad relative to the adjacent PCB `GND` test pad.
6. Compare the rail progression with the design path and the relevant component data. Account for D9 and Q25 conduction losses; do not invent a voltage-drop limit from nominal labels alone.

If the F1 output/D9 anode, D9 cathode, or another internal node is not safely accessible, power down and identify a safe large pad/test fixture before measuring. Do not require live probing of dense U2, D9, Q25, or neighboring pads where a slipped tip can short 24 V into another net.

### Output quality, startup, and load testing

- **DC accuracy:** record `3V3` with the DMM at no external load and at each defined operating load. Establish the allowable range from STM32 and connected-device requirements plus the power design target.
- **Ripple/noise:** use an oscilloscope probe with a short ground spring at the 3V3/GND test points. Record probe ratio, coupling, bandwidth limit, time base, load, and peak-to-peak result. A long ground lead can create a misleading waveform.
- **Startup:** capture `24V_PROTECTED` and `3V3` during supply enable. Check monotonic behavior, rise time, overshoot/undershoot, and reset release against the relevant device requirements. No waveform criterion is declared PASS until a limit is documented.
- **Load:** increase only with a known electronic load or known system loads, while recording input current, rail voltage, ripple, and temperatures. Remain within the ratings of F1, D9, Q25, LMR36510, L1, connectors, and wiring. Stop for instability or abnormal heating.
- **Abnormal supply tests:** reverse polarity, brownout, hot-plug, overvoltage, surge, and repeated power cycling require a separately reviewed setup and limits. They are not implied by ordinary 24 V bring-up.

## B3. STM32 Minimum-system Verification

### Connection

1. Confirm stable `3V3` at the board test point and normal boot strapping (`BOOT0` LOW and `BOOT1`/PB2 at its default LOW) before attaching the debugger.
2. With the target supply off, connect ST-Link `VTREF`, `GND`, `SWDIO` (PA13), `SWCLK` (PA14), and `NRST`; then power the target in the intended order.
3. Treat SWD `VTREF` as the target-voltage reference. Do not use it as the default power source for the complete 24 V industrial board.

### Test and expected behavior

- Confirm the debugger detects the target at the observed `VTREF` voltage.
- Record device identity, programming tool/version, firmware build or checksum, programming/verify result, and reset method.
- Verify boot from main flash after debugger reset and after a controlled board power cycle.
- Exercise the manual reset path and confirm the intended firmware restarts.
- Check the normal BOOT condition and, only when needed, the documented service-boot condition; restore BOOT0 before ordinary operation.
- Before enabling field functions, confirm firmware GPIO initialization matches the routing-driven mapping below and preserves Active-Low semantics.
- During reset and early initialization, measure the CM35 control terminals as specified in B5; the design expectation is that the external outputs remain inactive.

Failure to connect should be localized through `3V3/VTREF`, target GND, SWDIO/SWCLK continuity, NRST behavior, BOOT state, and firmware/tool settings. Do not erase or change hardware merely to mask an unstable power or reset condition.

## B4. USB-UART and Isolation Communication

The isolation boundary is:

```text
USB side:    USB_VBUS / USB_GND -> CH340C -> ISO7721 side 1
Machine side: 3V3 / GND         -> STM32  -> ISO7721 side 2
```

`USB_GND` and PCB `GND` must remain separate unless a deliberately reviewed external system connection creates a common path.

### Basic test

1. Power only the USB side and confirm USB VBUS at an accessible USB-domain point relative to `USB_GND`.
2. Confirm CH340C enumeration in the host OS and record the device/port identity and driver state.
3. Power the machine side from the protected 24 V input and confirm ISO7721 side 2 has `3V3` relative to PCB `GND`.
4. Run a bidirectional UART test with known baud, framing, message pattern, duration, and error count. Record transmitted and received data rather than only noting that a port opened.

### Required power-sequence matrix

Repeat communication/recovery checks for:

- USB first, then industrial/machine power;
- industrial/machine power first, then USB;
- both sides powered;
- USB-side removal while the machine side remains powered;
- machine-side removal while USB remains powered;
- USB unplug/replug and restoration of both enumeration and UART communication.

For each case, observe whether the UART idle state remains inactive/HIGH, whether spurious commands occur, and whether recovery needs a reset or application restart.

A normal non-isolated ST-Link connects its computer-side ground to PCB `GND`. If the same computer or grounded instruments are also connected to the USB domain, external cable/shield/earth paths may bridge `USB_GND` and PCB `GND`, defeat the intended isolation, or carry unwanted current. Before isolation-related testing, disconnect ST-Link or use an appropriately isolated debug arrangement and verify the complete grounding topology.

Successful enumeration and UART data exchange prove basic communication only. They do not prove isolation withstand, creepage compliance, ESD/EMC performance, or surge immunity.

## B5. Industrial Control Outputs — CN6 / CM35 IN11–IN18

Use the locked routing-driven mapping:

| CN6 signal | STM32 GPIO | Commanded expectation |
| --- | --- | --- |
| IN11 | PA8 | GPIO LOW = control active; GPIO HIGH = inactive |
| IN12 | PA11 | GPIO LOW = control active; GPIO HIGH = inactive |
| IN13 | PA12 | GPIO LOW = control active; GPIO HIGH = inactive |
| IN14 | PA15 | GPIO LOW = control active; GPIO HIGH = inactive |
| IN15 | PB4 | GPIO LOW = control active; GPIO HIGH = inactive |
| IN16 | PB5 | GPIO LOW = control active; GPIO HIGH = inactive |
| IN17 | PB6 | GPIO LOW = control active; GPIO HIGH = inactive |
| IN18 | PB7 | GPIO LOW = control active; GPIO HIGH = inactive |

CN6 is the CM35 IN11–IN18 connector. For voltage checks, use CM35 `G/24G` (PSU B `-V`, the same I/O-domain reference as PCB `GND`) as the 24 V-side reference. Do not reference these terminals to CM35 system `0V`/PSU A `-V`, `USB_GND`, PE, or an arbitrary oscilloscope earth.

For each channel:

1. Start with the host command inactive and record the host state, MCU logical state, GPIO level if observable, and CN6/CM35 terminal voltage.
2. Command only that channel active and repeat the measurements.
3. Return it inactive before moving to the next channel.
4. Confirm the application label and physical terminal agree with the table.

The design expectation is a 24 V-side HIGH/inactive state for GPIO HIGH and a pulled-low/active state for GPIO LOW. The prior practical debug observed approximately 24 V inactive and approximately 0 V active, but exact acceptance bands must come from the CM35 input specification and measured system conditions.

Also record all eight terminal states during MCU reset, before GPIO initialization, after firmware reset, during machine-side brownout, and during controlled power-down. The hardware design target is that MCU high-impedance/reset leaves the 2N7002 off and the CM35 input inactive; this remains a test requirement, not an assumed measured PASS.

## B6. CM35 Status Inputs — CN5 / OUT1–OUT8

Use the locked routing-driven mapping:

| CN5 signal | STM32 GPIO | Physical/software expectation |
| --- | --- | --- |
| OUT1 | PA2 | CM35 active pulls MCU input LOW; software reports active |
| OUT2 | PA3 | CM35 active pulls MCU input LOW; software reports active |
| OUT3 | PA4 | CM35 active pulls MCU input LOW; software reports active |
| OUT4 | PA5 | CM35 active pulls MCU input LOW; software reports active |
| OUT5 | PA6 | CM35 active pulls MCU input LOW; software reports active |
| OUT6 | PA7 | CM35 active pulls MCU input LOW; software reports active |
| OUT7 | PB10 | CM35 active pulls MCU input LOW; software reports active |
| OUT8 | PB11 | CM35 active pulls MCU input LOW; software reports active |

CN5 is the CM35 OUT1–OUT8 connector. Exercise one known CM35 output at a time using the correct PSU-B I/O-domain common. For both inactive and active states, record the field-terminal voltage, MCU-side logic level when safely observable, raw firmware value, interpreted software state, and host display. The physical input is Active-Low; the application meaning should be positive (for example, `active = true`) only after firmware inversion.

Complete a channel-by-channel table for OUT1 through OUT8, then test any combinations required by the application. A correct principle or one working channel is not evidence that all eight channels pass.

## B7. Photoelectric Sensor NO/NC Inputs

CN1–CN4 are Sensors 1–4. Each connector supplies `24V_PROTECTED` and PCB `GND` and accepts one NPN NO signal and one NPN NC signal. The final mapping is:

| Sensor | NO GPIO | NC GPIO |
| --- | --- | --- |
| Sensor 1 / CN1 | PB8 | PB9 |
| Sensor 2 / CN2 | PA0 | PA1 |
| Sensor 3 / CN3 | PB12 | PB13 |
| Sensor 4 / CN4 | PB14 | PB15 |

For each sensor:

1. Verify brown/blue/black/white wiring against the connector pinout before power is applied.
2. Record `24V_PROTECTED` at the connector relative to PCB `GND` with the sensor connected.
3. Record NO and NC field voltages, MCU-side logic values, and host indications in the untriggered state.
4. Trigger the sensor using a repeatable target and record the same data.
5. Repeat several transitions and confirm the steady states are complementary after the switching interval.

The field outputs are NPN Active-Low. A sinking/asserted field output is expected to produce MCU LOW; a released output is expected to produce MCU HIGH. NO/NC can be briefly non-complementary while switching, so distinguish a short transition from persistent both-active, both-inactive, open-wire, swapped-wire, or stuck-channel behavior. The NO/NC principle is not a substitute for actual validation of all eight inputs.

## B8. System Integration

The project uses three relevant supply domains:

```text
PSU A system domain:
  PSU A +24 V / -V -> CM35 system 24V / 0V

PSU B isolated I/O domain:
  PSU B +24 V / -V -> CM35 V / G / 24G
  PSU B +24 V / -V -> PCB 24V_IN_RAW / GND_IN_RAW
  PCB 24V_PROTECTED / GND -> M4 pull-ups and CN1-CN4 sensors
  PCB 3V3 / GND -> STM32 and ISO7721 machine side

USB domain:
  Host USB -> USB_VBUS / USB_GND -> CH340C and ISO7721 USB side
```

PSU A `-V` must not be assumed equal to PSU B `-V`; the CM35 system side and isolated I/O side must follow the CM35 wiring documentation. CM35 `V/G/24G` is cabinet-powered from PSU B, not supplied through PCB F1. The USB domain is separately powered by the host.

After B1–B7 are individually satisfactory, integrate in this order:

1. Apply PSU A and PSU B according to the reviewed CM35/system wiring procedure; verify the intended domain references before connecting USB or instruments.
2. Confirm PCB power and MCU boot.
3. Establish USB-UART and confirm no unintended cross-domain ground path.
4. Exercise one CM35 control output, then all required controls.
5. Exercise one CM35 status output, then all required status inputs.
6. Connect and validate one sensor, then Sensors 1–4.
7. Run the host workflow while correlating commands, physical terminal voltages, CM35 states, sensor states, and host indications.

Keep **basic functional testing** separate from **extended validation**. Basic testing demonstrates intended commands and indications under nominal conditions. Extended validation covers all channels, repeated cycles, timing, long-duration operation, load extremes, supply sequencing/brownout, thermal behavior, cable effects, ESD/EMC, surge, and isolation withstand; each requires explicit conditions and limits.

## B9. Multimeter and Instrument Safety

- For voltage, place the red lead in the `V/Ω` jack and measure in parallel across the node and the correct domain reference.
- For current, use the correctly rated current jack/range and insert the meter in series. Confirm meter fuse/rating and expected current before energizing.
- For resistance or continuity, use the `V/Ω` jack with all sources removed and capacitors discharged.
- After any current measurement, return the lead to the `V/Ω` jack before the next voltage measurement.
- Never place a DMM configured for current directly in parallel across the 24 V supply or a powered rail.
- Select the reference for the domain being measured: `GND_IN_RAW` for the raw input pair, PCB `GND`/PSU B `-V`/CM35 `G/24G` for the machine I/O domain, `USB_GND` for the USB domain, and PSU A `-V`/CM35 `0V` only for the CM35 system domain.
- A conventional bench-oscilloscope ground clip is normally earth-referenced. Attaching it can short two nominally isolated domains or bypass Q25. Determine the complete grounding path before connection; use appropriate differential or isolated measurement equipment when needed.
- Use insulated probe tips, one-hand/controlled probing practices where appropriate, secure the return lead first, and power down before moving clips in dense areas.
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

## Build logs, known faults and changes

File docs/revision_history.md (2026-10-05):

# Hardware Revision History

## Rev.C — Current Hardware

Status:

- Third hardware iteration
- Hardware fabricated and assembled
- Basic functional bring-up and debugging completed
- Currently in practical use

Major changes from the previous revision:

- Added photoelectric-sensor field power and NO / NC signal interfaces
- Added onboard USB-C and CH340C USB-UART communication
- Added ISO7721 digital isolation between USB-side and machine-side domains
- Replaced the external STM32 minimum-system module with an onboard STM32 minimum system
- Added or improved 24 V reverse-polarity, input, and onboard power-conversion protection boundaries

Validation boundary:

Rev.C has completed practical functional debugging and is in use, but the repository does not claim complete quantified electrical characterization, EMC/surge qualification, isolation-withstand certification, or full formal system acceptance.

## Earlier Iterations

Rev.A and Rev.B existed as previous hardware iterations. Their detailed circuit changes, dates, and test histories are not reconstructed in this repository.

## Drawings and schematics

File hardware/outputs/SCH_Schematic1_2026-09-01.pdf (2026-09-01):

# M2 STM32F103C8T6 Minimum System M5 Photoelectric Sensor Interface

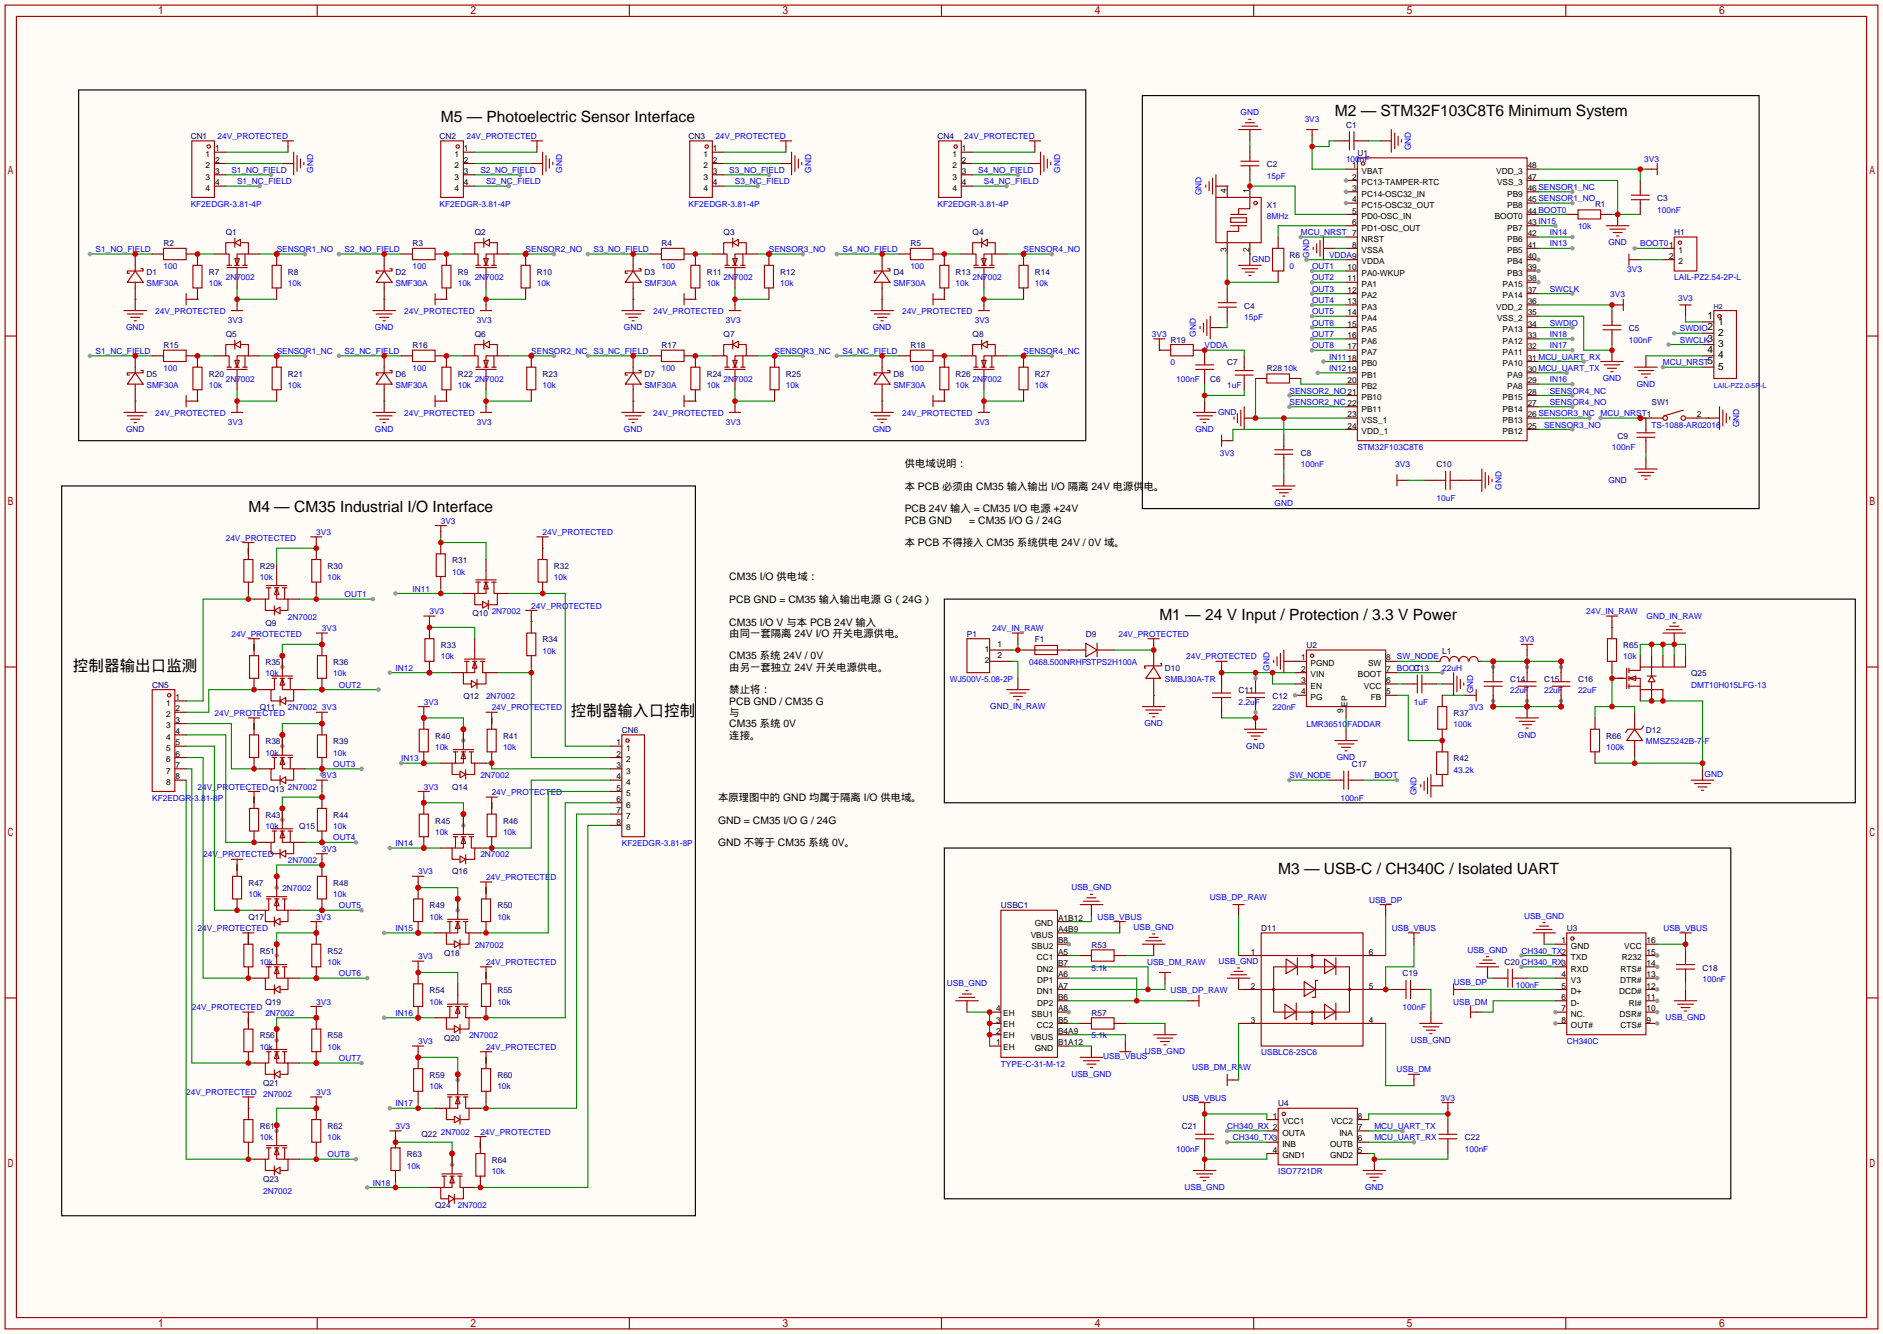
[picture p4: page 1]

本 PCB 必须由 CM35 输入输出 I/O 隔离 24V 电源供电。
PCB 24V 输入 = CM35 I/O 电源 +24V
本 PCB 不得接入 CM35 系统供电 24V / 0V 域。

本原理图中的 GND 均属于隔离 I/O 供电域。
GND = CM35 I/O G / 24G
GND 不等于 CM35 系统 0V。

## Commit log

2026-08-29 Initialize STM32 24V industrial I/O bridge
2026-08-29 Close Gate 1.5 and enter component selection
    [旧BOM表.xlsx]
2026-08-29 Clarify Stage 2 plan maintenance wording
2026-08-29 Repin framework to development-v1.2.0
2026-08-29 Close out Stage 2 component selection
2026-08-31 docs: enter Stage 3 module design
2026-08-31 docs: record M3 isolated USB UART design
2026-08-31 docs: clean up Stage 3 interface records
2026-08-31 docs: close Stage 3 module design
2026-09-01 docs: sync Stage 4 schematic review decisions
2026-09-01 docs: close Stage 4 and enter PCB layout
    [BOM_Board1_Schematic1_2026-09-01.xlsx]
2026-09-01 chore: repin development framework evaluation
2026-09-01 chore: repin framework stage 5 rules
2026-09-02 docs: synchronize PCB layout preflight rules
2026-09-02 docs: record PCB mechanical baseline
2026-09-02 docs: sync CM35 connector placement mapping
2026-09-02 docs: close Stage 5 placement baseline
2026-09-02 docs: record Stage 5 placement closeout
2026-09-02 docs: enter Stage 6 routing
2026-09-03 docs: record Stage 6 routing closeout state
2026-09-03 docs: prepare final Stage 6 PCB review
2026-09-03 docs: sync implemented Stage 6 PCB rules
2026-09-03 docs: sync stage 6 pcb rule baseline
2026-09-03 docs: record stage 6 drc disposition
2026-09-03 docs: refresh stage 6 project status
2026-09-04 docs: record pcb mask rule baseline
2026-09-04 docs: sync M1 final power corrections
2026-09-04 docs: record stage 6 schematic corrections
2026-09-04 docs: sync stage 6 finalization status
2026-09-04 docs: record stage 6 routing closeout status
2026-09-04 docs: record PCB fabrication release readiness
2026-09-04 docs: close PCB fabrication review
2026-10-05 docs: prepare industrial IO bridge for public portfolio
    [P1.schdoc, PCB1.PcbLib, STM32 24V Industrial IO Bridge.PcbDoc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]
2026-10-30 docs: record Oct 30 Rev.C buck output ripple observation
2026-10-30 docs: distinguish measured basic buck ripple from deferred power tests
2026-10-30 docs: link M1 power review to bounded buck ripple observation
